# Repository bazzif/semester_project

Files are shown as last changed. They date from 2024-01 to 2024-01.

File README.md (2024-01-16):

# ElectorRing - Touch detection by coupling RF Signal to body

PCB

The electric ring can be used to detect the pinching of one's own fingers or the pinching of other people. The principle of operation is based on a transmitter that couples a high frequency signal into the body, which is measured by a receiver and amplified 30 times. This signal is then read by a microcontroller and can send a signal to a PC via BLE. 

Here is an overview of the outputs of the PCB that was developed as part of the semester project. It serves as an overview for debugging and pin 1 of the Seeed XIAO BLE must be connected to pin 1 of the PCB. 

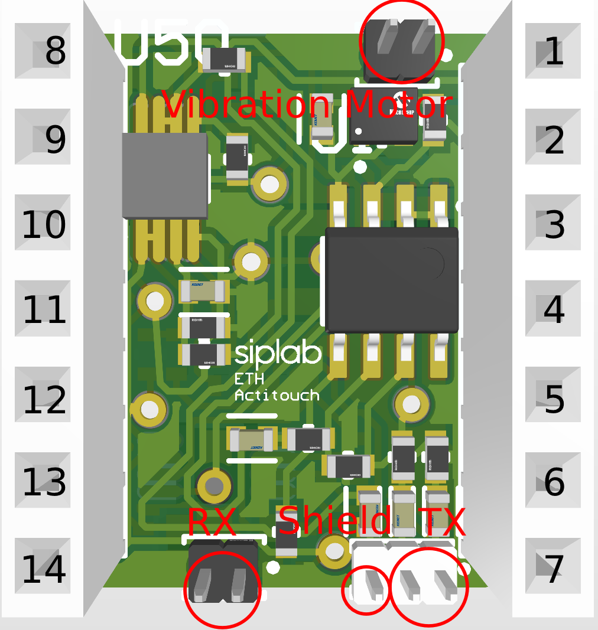
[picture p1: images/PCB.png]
PCB


## Assembly
- The assembly instruction can be found [here](https://github.com/eth-siplab-students/t-st-2022-WearableTouchDetection-FabioBazzi/blob/master/source/Insturctions/Assembly%20instructions.pdf) 
- Upload the [code](https://github.com/eth-siplab-students/t-st-2022-WearableTouchDetection-FabioBazzi/blob/master/source/firmware/BLEDataSendToPeripheral/BLEDataSendToPeripheral.ino) on the ring
- Upload the [code](https://github.com/eth-siplab-students/t-st-2022-WearableTouchDetection-FabioBazzi/blob/master/source/firmware/BLEMouseController/BLEMouseController.ino) on the Seeed XIAO BLE connected to your PC

## Callibration
It may be that the default programme does not work as desired because the ring was calibrated to me at the beginning, this section explains how I went about calibrating the ring.
- Connect the ring to the computer and [upload and run]([https://github.com/eth-siplab-students/t-st-2022-WearableTouchDetection-FabioBazzi/blob/master/source/Arduino%20Code/BLEDataSendToPeripheral/BLEDataSendToPeripheral.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](https://github.com/eth-siplab-students/t-st-2022-WearableTouchDetection-FabioBazzi/blob/master/source/Arduino%20Code/Callibration/Callibration.ino))
- Check what with the Serial Plotter of the Arduino what the Signal Strength of **Pinch** and **No Pinch** is
- Select the threshold value between pinch and no pinch. Set a suitable hysteresis to make the state more robust
- Edit the [code](https://github.com/eth-siplab-students/t-st-2022-WearableTouchDetection-FabioBazzi/blob/master/source/firmware/Callibration/Callibration.ino) and uplode

      #define HYST xx
      #define THRESHOLD xx 
      
## Further development
- Improve the ceramic filter problem by perhaps converting it to a high-pass filter that filters frequencies below a certain threshold.
- Instead of using the sum of the FFT to detect a detection, a digital Goertzel filter should be used. This requires less computing time than the FFT and is more frequency specific. That means instead of calculating the whole frequency spectrum only one frequency of the signal is not suppressed e.g. the undersampled 10.7 Mhz.
- Increase the sampling frequency of the Seeed XIAO BLE. Currently the sampling speed is limited by analog read. By rewriting the register of the microcontroller it should be possible to increase it up to 70 kHZ. 

## Debug
This section describes the bugs and debugging that I encountered while making the electro ring.
### Hardware
  - **Ceramic bandpass filter (10.7 MHZ):** It sometimes happened that the bandpass filter filtered the signal too much so that no signal could pass through the filter. In this case I have then shorted the filter with a cable .
  - **Soldering:** Make sure all solder joints are clean and in contact with the PCB. To test if the PCB is working, it is recommended to test the three sub-circuits (transmitter, receiver and shield) independently and see if they work. 
    - **Transmitter:** Connect ground to pin 2 and 3.3 V of the power supply to pin 3 and measure the signal at the transimitter output with the DSO. 

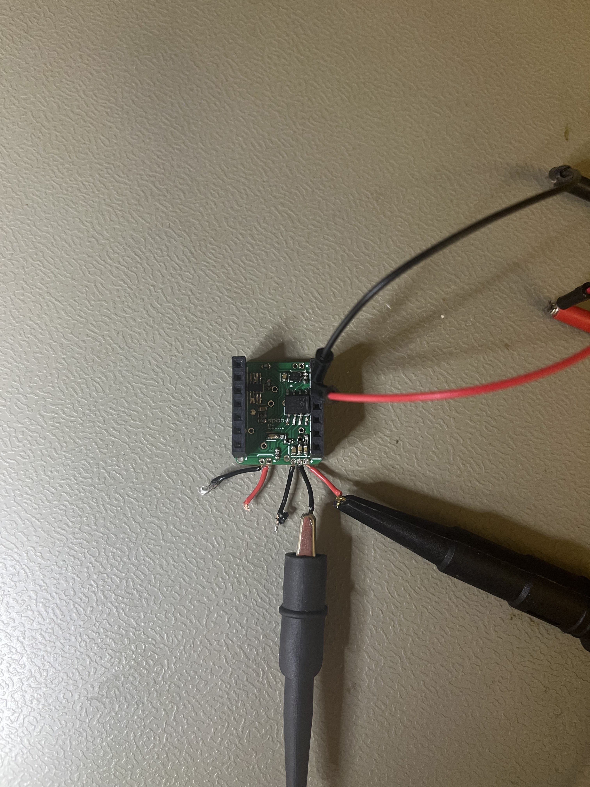
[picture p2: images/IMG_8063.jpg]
      
      
      The measured Signal should look similar to this:
      
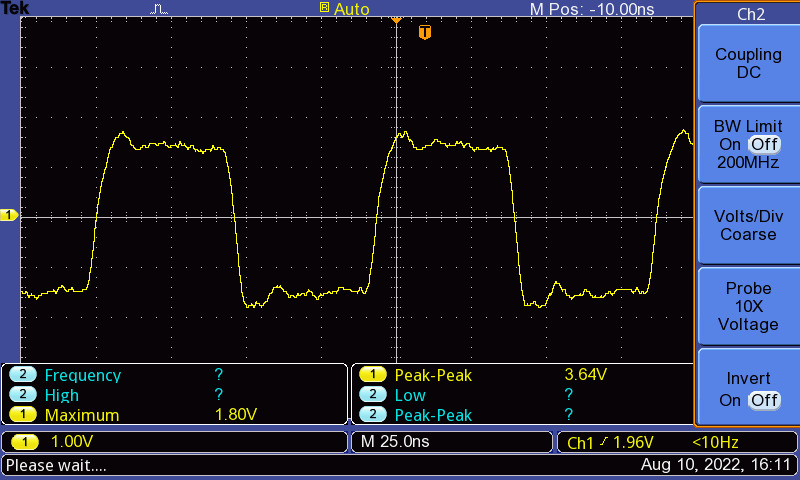
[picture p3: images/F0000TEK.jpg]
      
      
    - **Shield:** Connect ground to pin 2 and 3.3 V of the power supply to pin 3 and measure the voltage behind the capacitor which leads to the shield output.
    
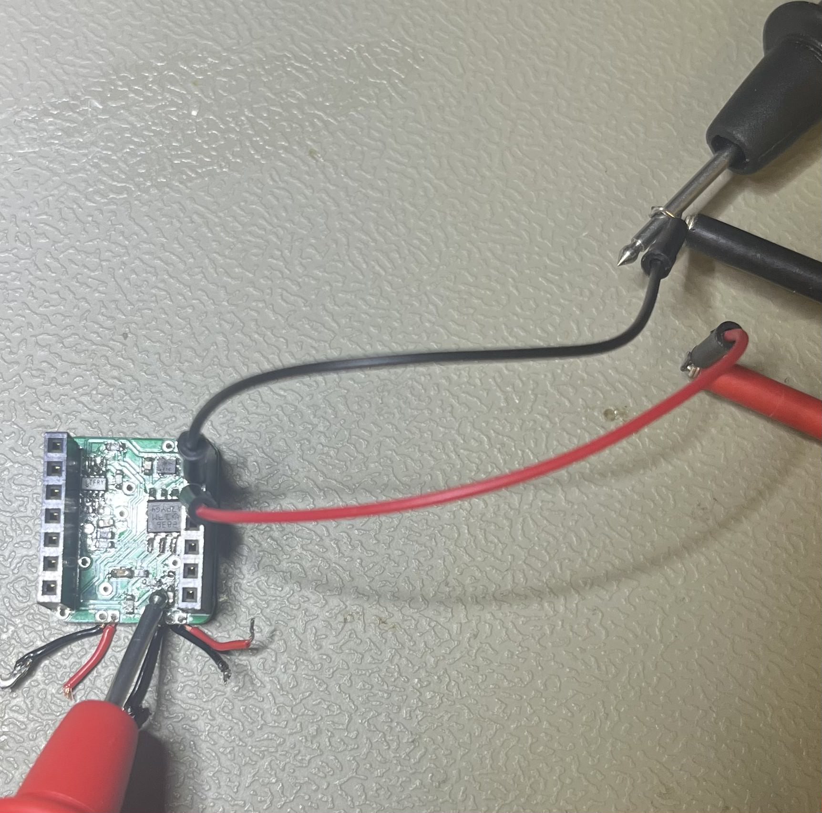
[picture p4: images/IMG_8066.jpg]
      
    
    - **Receiver:**  Connect ground to pin 2 and 3.3 V of the power supply to pin 3. Connect the frequency genrator with the receiver. Generate a sinusoidal signal with a frequency of 10.7 mhz and an amplitude of 50 mV. The gain of the receiver should amplify the signal by a factor of 30 and can be measured at pin 1 with the DSO.
    
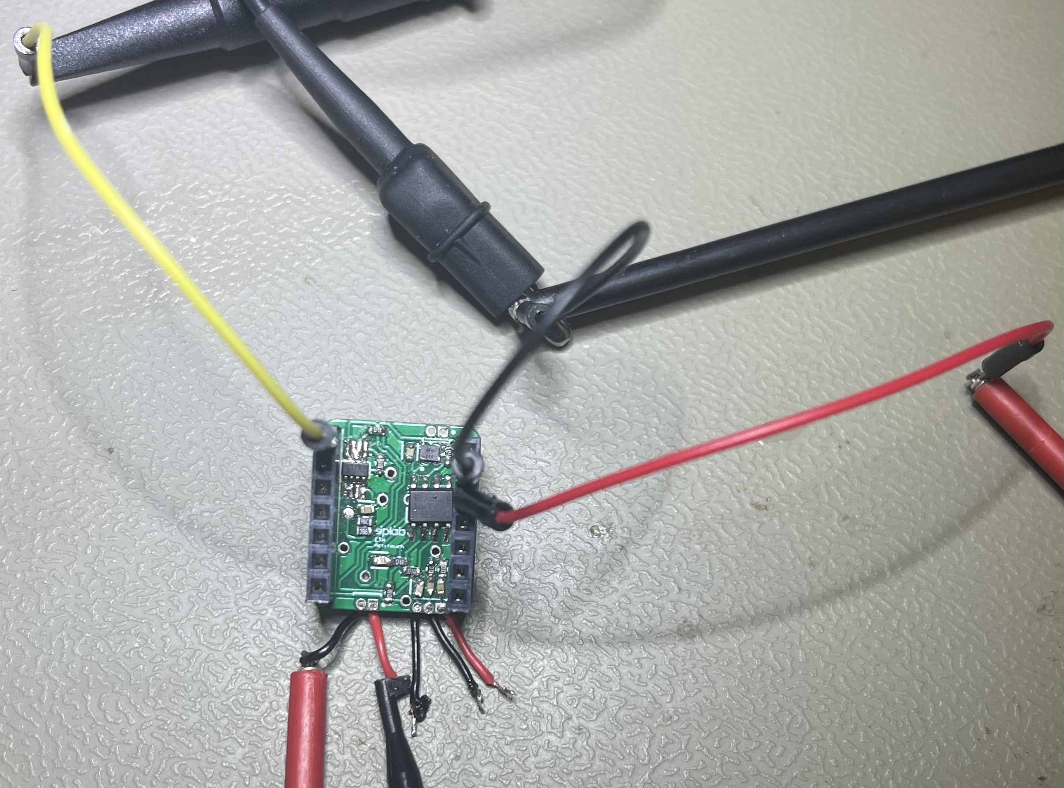
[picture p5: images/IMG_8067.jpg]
      
    
      The measured Signal should look similar to this:
    
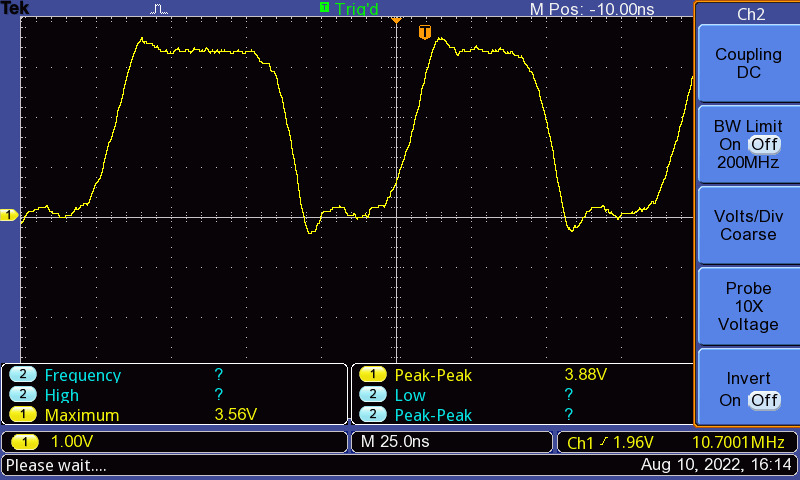
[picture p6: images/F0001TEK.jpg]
      
    
### Interface Seeed XIAO BLE and PC
 - **Board manager:** Make sure you have the latest version of Seeed XIAO BLE - nRF52840 board installed
 - **upload.tool.serial:** If you get the following error message when uploading your code to the Seeed XIAO BLE in the Arduino IDE 2.0.0, follow this [instruction](https://forum.arduino.cc/t/arduino-2-beta-12-stlink-programmer-error/921351) (at point 9. use this line **xiaonRF52840.upload.tool.default=nrfutil**)

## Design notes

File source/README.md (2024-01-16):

## Seeed XIAO BLE Code
The code for the Seeed XIAO BLE can be found in firmware it contains
- Calibration : Calculates the average of the DFT coefficients and visualizes them. Used to calibrate the ring for the carrier
- BLEMouseController : Makes connection to a second device and receives a pinch state and executes a mouse click on the computer 
- BLEDataSendToPeripheral : Make connection to a second device and detectes a pinch and send it
## Python Code 
A Python script to visualize measurements by recording the serial output of the Seeed XIAO BLE with Putty. There are 3 scripts
- Pinch_measurment.py : Visualization of the FFT coefficients for pinch and no pinch
- SNR.py : Visualization of the SNR for all three test subjects as a box plot
- Latency_measurement.py: Visualization of the Latency as a box plot
This folder also contains all the measurements that were performed with the electroring
## CAD
Contains all CAD files as STEP files and STL files to make the ring. There is also an additional gcode file that can be used directly to make a 3d print with the Ultimaker2+
## PCB
All flies to creat the PCB and generate a Part list as well as the schemas that are used to correctly assign the components to the PCB

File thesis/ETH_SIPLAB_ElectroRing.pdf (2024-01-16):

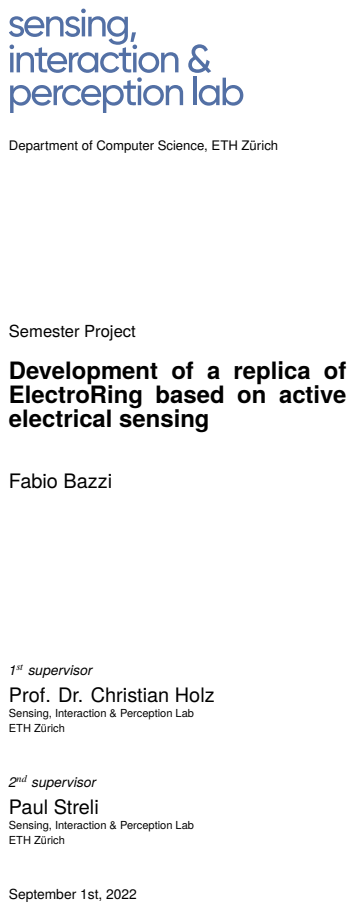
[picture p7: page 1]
Fabio Bazzi; nd supervisor Paul Streli; September 1st, 2022

Department of Computer Science, ETH Zürich

Semester Project
Development of a replica of
ElectroRing based on active
electrical sensing

st supervisor
Prof. Dr. Christian Holz

Sensing, Interaction & Perception Lab
ETH Zürich

Fabio Bazzi
Development of a replica of ElectroRing based on active electrical sensing
Semester Project, September 1st, 2022
Supervisors: Prof. Dr. Christian Holz and Paul Streli

ETH Zürich
Department of Computer Science, ETH Zürich Universitätstrasse 6
8092 Zürich

# Development of a replica of ElectroRing based on active electrical sensing

Fabio Bazzi
Sensing, Interaction & Perception Lab Department of Computer Science, ETH Zürich bazzif@ethz.ch

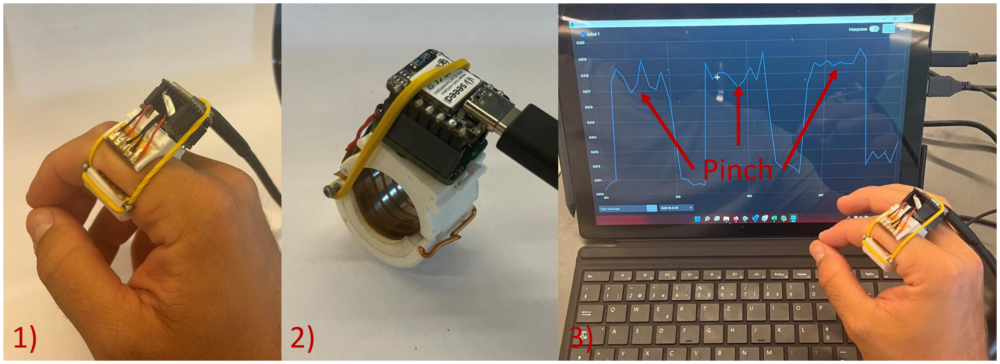
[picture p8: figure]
Pinch

Figure 1. 1) Replica of the ElectroRing worn on the index finger, 2) 3-D printed case with PCB mounted and flexPCB attached on the inside with a rubber band closure, and 3) Raw Real-time data from measured pinches.

ABSTRACT
As part of the semester project, a replica of the ElectroRing presented in the work of Kienzle et al. [1] was developed. The technology is based on electrically active sensing and is used to detect the creation of touches and the release of touches on the own body.

As part of the project, a printed circuit board (PCB) was developed that enables electronic active sensing. With a Seeed XAIO BLE the signal of the PCB was measured and processed with the discrete Fourier transform (DFT). Using a threshold, the signal is converted into a pinch state. This state is then sent to a peripheral device via BLE. All parts are held together by a 3D printed housing that can be attached to the index finger.

The replica of the ElectroRing was further tested for signal to noise ratio (SNR) with an average of 25 dB and an average latency of 130 ms. As an application example, the ring was configured to use a pinch as a mouse click input on the computer.

The documentation of the project is available at the following Github repository (https://github.com/eth-siplab-students/t-st-2022-WearableTouchDetection-FabioBazzi)

Keywords
Touch and pinch detection; mixed reality.

INTRODUCTION
Computers play an essential role in human interaction. Since the development of the personal computer, several waves of computer innovation have advanced computer technology. A new wave of innovation that integrate virtual reality (VR) and augmented reality (AR) into human daily life is emerging. [3]

Already today there are various devices that visualize VR and AR in high resolution, but the input devices that simplify interaction with VR and AR are not yet as advanced. [2]

The ElectroRing is an example of a VR and AR wearable interaction device. It can be used to detect pinching and touching the body as well as its release. This is especially useful in AR applications because it is difficult to detect touches with head mounted cameras when the fingers hover above the surface.

ElectroRing can therefore be used in AR applications. For example, a button can be projected on the human body and the pressing of the button can be measured with the ElectroRing.

The ElectorRing can not only be used for VR and AR applications, but it is also possible to use it with a personal computer to provide a new interaction experience for the user.

This technology has many application potentials, which makes the ElectroRing interesting for the research group SIP of the

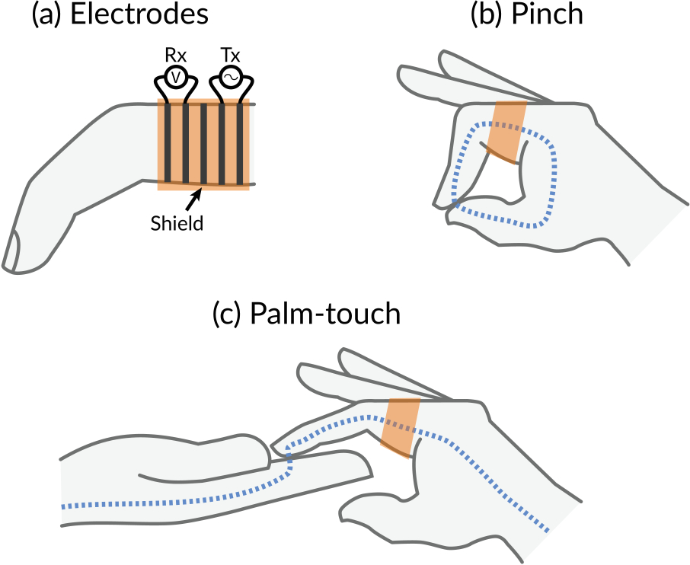
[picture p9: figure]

Figure 2. “(a) ElectroRing uses five electrodes: two transmit electrodes (closest to the palm) differentially couple the AC signal to the finger, the middle electrode shields direct coupling between the Tx and Rx electrodes, two receive electrodes (distal) measure the gradient of the signal along the finger. (b) During a pinch, the signal travels through the thumb and galvanically back to the transmit electrode. (c) Touching the opposing palm creates a galvanic path through the body back to the proximal transmit electrode. ” [1]

ETH Zurich and therefore a replica of the ElectroRing was created in this project.

Theory of Operation
In Figure 2 the theory of operation of ElectroRing is shown. In summary, the ring works by coupling a 10.7 MHz square wave of 3.3 volts with two transmitting electrodes on the body. When no galvanic contact between the transmitter and the receiver (e.g. Pinch or Palm-touch) exists most of the signal flows between the two transmitter electrodes. An electrical shield in the middle prevents the transmitter to directly couple with the receiver. When a galvanic path is closed by a pinch, the two receiver electrodes measure the gradient of the signal along the finger.

For more and deeper explanation on the principle of effect, the work of Kienzle et al. [1] is recommended.

RELATED WORK
There are already various systems for segmenting touches, with an electro active sensing system. The work of Kienzle et al. [1] is about the ElectroRing which served as a basis to create a replica in this semester project. In another work of Zahng et al. [5] a bracelet is used, called ActiTouch. The ElectroRing is based on the ActiTouch, but it has an electrical shield between the receiver and the transmitter. Therefore the ElectroRing simplifies instrumentation by requiring only one instrumentation location instead of two as the ActiTouch does.

ElectroRing
The paper describes the principle of operation, the production of the ElectroRing and measurement results. In addition, the ring described in the paper has an integrated IMU-2-D tracking system, with which they concluded that the sensing technology is largely independent of gestures velocity or the mechanical action at contact with a 25 dBV SNR. They have also shown in further work that there is a potential to use the ElectroRing to detect various electrically conductive materials by touch. [1]

ActiTouch
With ActiTouch, the transmitter electrodes are attached to a wristband and receiver electrodes are attached to a headmounted display. ActiTouch, unlike ElectroRing, does not include an active shield. This causes the receiver electrode to become saturated when the transmitter and receiver electrodes are close together, resulting in poor sensitivity to touch. This makes it impossible to incorporate active electronic sensing technology in a single small device. According to their paper, the best material for the electrodes is silver fabric which are galvanically arranged longitudinally to each other. Further they have shown with a frequency swept that the best signal to noise results are reached at the frequency 10.5 MHz. Also they have not found negative health effects on the human body using this measurement principle. [5]

IMPLEMENTATION
Hardware and software was developed for the replica of ElectroRing. In order for the replica of ElectroRing to measure signals and communicate with peripheral devices, a micro controller was used. Further, a printed circuit board (PCB) was designed, which contains signal generation, the electrical shield and a measurement gain. In addition, a ring was designed to hold all the parts together and to attach the system to the finger in a portable way. The hardware was then programmed which allows to measure a pinch state and to send it to a peripheral device. Finally, an application example was created to demonstrate the potential of the replica of ElectroRing and measure latency. 4

Hardware
Electronics
The electronics of the replica of ElectroRing consist of a PCB and a Seeed XIAO BLE. The PCB is used for signal generation and amplification and the Seeed XIAO BLE is used for measurement and communication. The PCB contains a transmitter, receiver and a shield. The transmitter generates a 3.3V 10.7 MHz rectangular signal that is then coupled to the body over electrodes. The receiver is an instrumentation amplifier with a gain of 30 and with electrodes contacted to the body. Located between receiver and transmitter is the shield electrode with a potential of 1.65 volt. The electronics are powered by a 3.7 V battery with 40 mAh. The current for the operation was measured with a Fluke 115 and is 60 mA, therefore the replica of ElectroRing can be theoretically be powered for 40 minutes.

Housing
The housing to hold and attach the PCB to the finger is 3-D printed with PLA. A flexPCB with a conductor width of 2 mm and a distance of 1 mm between the conductor paths is used to connect the receiver, transmitter and shield to the finger. A sealing material is glued inside the ring to ensure the contact of the conductive lines with the finger and to increase the wearing

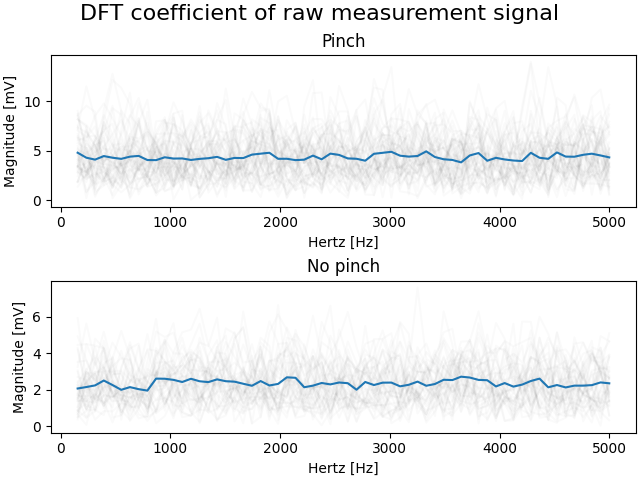
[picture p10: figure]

Figure 3. The blue line is the mean value of the DFT coefficient for multiple measurement bins, while the black lines are the DFT coefficients for consecutive bins of 128 samples, the signal was sampled at 10 kHz.

comfort. With double sided tape the flexPCB is attached to the seal. The ring is closed by means of a rubber band.

Software
The signal of the receiver is undersampled with the Seeed XIAO BLE’s maximum standard sampling rate of 10 kHz. The original intention was to calculate the DFT coefficients by using 128 samples to determine a frequency range that rises during pinching, and then to use a Goertzel filter to filter the frequency associated with the pinch. However, when evaluating the DFT coefficients, no particular frequency could be found which increased alone when the galvanic path was closed. It was found that all coefficients except the first coefficient, which belongs to the DC current, changed significantly when pinched, as one can see in Figure 3. For this reason, the average of the DFT coefficients, except the first coefficient, was calculated. When the average of the DFT coefficients exceeded a medium threshold with hysteresis, a pinch state is detected. If this is undershot, a pinch release is detected. However, these values do not work unconditionally for every user and the replica of the ElectroRing must be recalibrated after the user changes.

EVALUATION
Two evaluations were performed using the replica of the ElectroRing.
1. Latency measurement
2. Signal to noise ratio (SNR) measurement

Apparatus for latency
To measure the latency, the ring was attached to the index finger. In the front of a screen of the computer with a visible running power point presentation, the index finger was filmed with an iPhone 12 Pro in slow motion with 240 FPS. By pinching the finger the Seeed XIAO BLE detected the pinch and sent it a via BLE to a second Seeed XIAO BLE connected to the Computer. The second microcontroller connected to the
Test subject | Threshold [mV] | Hysteresis [mv]
1 | 0.016 | 0.003
2 | 0.011 | 0.02
3 | 0.013 | 0.002

Table 1. Threshold and hysteresis values for the three test subjects

Test subject | mean | SD
1 | 15.81 dB | 0.40
2 | 29.72 dB | 0.39
3 | 28.73 dB | 0.47

Table 2. Mean and SD of SNR for all test subjects

computer generated a mouse click. Thus a change of slides was triggered. The latency can be calculated by the frame rate and counting the number of frames that elapse between the pinch and the slide change.

Apparatus for SNR
The SNR was measured for 3 different people with the ElectroRing attached to the index finger. The ElectroRing was initially calibrated for each person connected to the computer. The ring is calibrated by considering the signal described in subsection 3.2 for pinch and no pinch for a given person, then both middle threshold and hysteresis are set empirically. The values can be seen in Table 1. The three different test subjects had to switch five times between pinch and non-pinch state. The signal from subsection 3.2 was recorded and saved with PuTTY to the disk and the SNR was calculated according the equation Equation 1.

SNR = 20log10(

mean(vtouch)−mean(vno−touch)

SD(vnoise)

) (1)

“vtouch are samples from a touch segment, vno−touch are samples from a non-touch segment, and vnoise are samples from the preceding non-touch segment.”[1].

RESULTS
The data generated from the replica of the ElectroRing evaluation was processed in Python, using the packages Pandas, Scipy and Matplotlib.

Latency
The result of the latency measurement is shown in Figure 4 as a box plot. On average the latency is 130 milliseconds (ms) (SD = 21 ms) to detect a pinch, send it to a second device and execute an input action on a personal computer.

Signal to Noise
The results of the SNR measurements are shown in Figure 5. The mean and SD are summarized in Table 2.

Every pinch was detected correctly, so the precision given Equation 2 and recall given Equation 3 were perfect.

precision =

TP
TP+FP

(2)

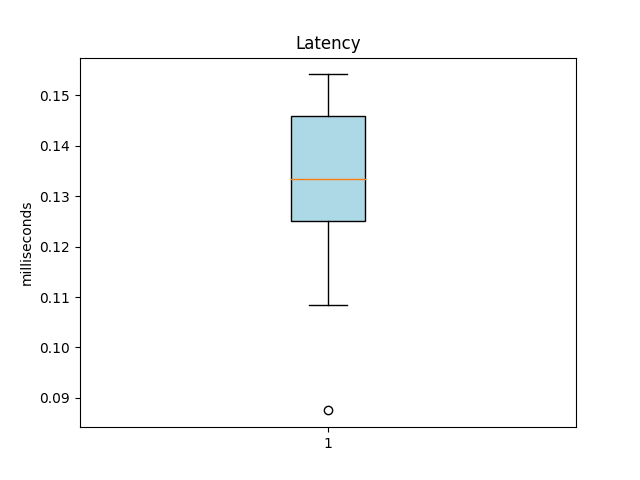
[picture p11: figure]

Figure 4. Measured latency due to pinch to trigger an action on the personal computer

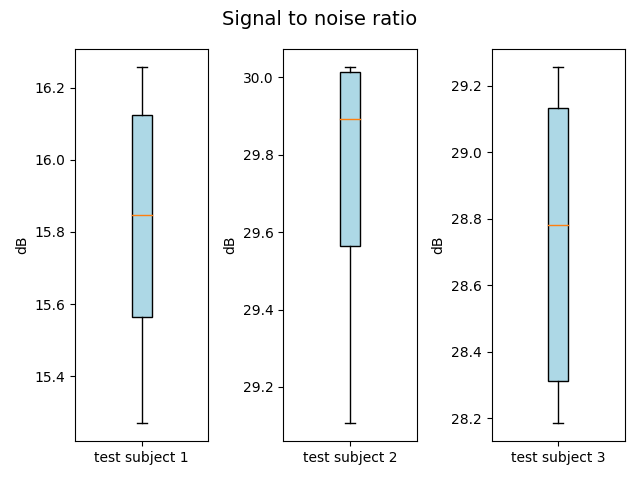
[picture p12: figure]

Figure 5. Caption

precision =

TP
TP+FN

(3)

With:

true positive (TP) : Pinch correctly detected

false positive (FP) : Pinch falsely detected

false negative (FN) : Pinch not detected

DISCUSSION
In this project, a replica of ElectroRing was built to detect touch. The viability of the ring was validated in two experiments. With a latency of 130 ms (SD = 21ms), the latency is acceptable based on the work of Ritter et al. [4]. Furthermore, the SNR of over 15 dB provides a sufficiently robust touch detection with a perfect recall and precision. However, it must be taken into account that the threshold and hysteresis must be individually tuned to detect touch.

Both latency and SNR can be further optimized by improving the software of the replica of ElectroRing. Instead of calculating the average of all DFT coefficients except the first, it could be more useful to determine the exact frequency band that rises during pinching and then to filter it with an appropriate bandpass filter. This partially reduces the computation time of the code and improves latency. It also improves the robustness. If all DFT coefficients except the first are considered, other signals with a different operating frequency than the ElectroRing that are coupled to the body can also have an influence. This on the other hand simplifies the tuning of the ring and makes it even more robust and user-friendly. One approach could be to increase the sampling rate when reading the signal to determine a unique frequency and then filter it with a Gortzel filter to detect touch.

If the replica of the ElectroRing is operated by the computer there are no misdetections of a pinch. When powered only by the battery and not connected to the computer, misdetections occur but only rarely. This may be due to the fact that the ring is powered by 5 volts when connected to the computer, and 3.7 volts when powered by the battery. To see how the behaviour of the ring changes when powered by the battery, the next step should be to transmit not only the pinch state via BLE, but also the signal described in subsection 3.2.

CONCLUSION
During the semester project, a Working MVP of the ElectroRing was developed based on the work of Kienzle et al. [1]. With the evaluation it was shown that the SNR is sufficient to detect the pinch state reliably. Further, with a low latency it was shown that the responsiveness of the ring is sufficient to ensure a acceptable human computer interaction.

REFERENCES
[1] Wolf Kienzle, Eric Whitmire, Chris Rittaler, and Hrvoje Benko. 2021. Electroring: Subtle pinch and touch detection with a ring. In Proceedings of the 2021 CHI

Conference on Human Factors in Computing Systems. 1–12.

[2] Hai-Ning Liang, Yuwei Shi, Feiyu Lu, Jizhou Yang, and Konstantinos Papangelis. 2016. VRMController: an input device for navigation activities in virtual reality environments. In Proceedings of the 15th ACM SIGGRAPH Conference on Virtual-Reality Continuum and Its Applications in Industry-Volume 1. 455–460.
[3] Stylianos Mystakidis. 2022. Metaverse. Encyclopedia 2, 1 (2022), 486–497.
[4] Walter Ritter, Guido Kempter, and Tobias Werner. 2015. User-Acceptance of Latency in Touch Interactions. In Universal Access in Human-Computer Interaction. Access to Interaction, Margherita Antona and Constantine Stephanidis (Eds.). Springer International Publishing, Cham, 139–147.
[5] Yang Zhang, Wolf Kienzle, Yanjun Ma, Shiu S Ng, Hrvoje Benko, and Chris Harrison. 2019. ActiTouch: Robust touch detection for on-skin AR/VR interfaces. In Proceedings of the 32nd Annual ACM Symposium on User Interface Software and Technology. 1151–1159.

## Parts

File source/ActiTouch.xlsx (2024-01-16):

Comment | Description | Designator | Footprint | LibRef | Quantity | Price/Pice [CHF] | Price [CHF] | Link
LS4448GS08 | Schottky Barrier Diode, 2-Pin SOD-323, Pb-Free, Tape and Reel | D1 | ONSC-SOD-323-2-477-02_V | CMP-1055-00462-1 | 1 | 0.18 | 0.18 | https://www.digikey.ch/de/products/detail/vishay-general-semiconductor-diodes-division/LS4448GS08/4810586
LT Q39E-Q1OO-25-1 | LED GREEN 0603 SMD | D? | FP-6_541-5056_01-4-MFG | CMP-02520-000009-1 | 1 | 0.42 | 0.42 | https://www.digikey.ch/de/products/detail/osram-opto-semiconductors-inc/LT-Q39E-Q1OO-25-1/2793415
CDSCB10M7GA121-R0 | Ceramic Filter 10.7MHz 2-Pin Surface Mount Emboss T/R | FL1 | FP-CDSCB10M7GA121-R0-MFG | CMP-06047-000004-1 | 1 | 1.11 | 1.11 | https://www.digikey.ch/de/products/detail/murata-electronics/CDSCB10M7GA135-R0/1219357
SSQ-107-01-G-S | SQ Post Socket, Through-hole, Vertical, -55 to 125 degC, 2.54 mm Pitch, 7-Pin, Female, RoHS | J1, J2 | SMTC-SSQ-107-01-X-S | CMP-1023-00284-1 | 2 | 1.46 | 2.92 | https://www.digikey.ch/de/products/detail/samtec-inc/SSQ-107-01-G-S/1110612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
GRPB021VWVN-RC | CONN HEADER VERT 2POS 1.27MM | J3 | FP-GRPB021VWVN-RC-MFG | CMP-2000-06371-2 | 1 | 0.24 | 0.24 | https://www.digikey.ch/de/products/detail/sullins-connector-solutions/GRPB021VWVN-RC/1786438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
Inductor | Inductor | L? | 0402-A | Inductor | 1 |  | 0
S2B-PH-SM4-TB(LF)(SN) | Male Header, Pitch 2 mm, 1 x 2 Position, Height 5.5 mm, -25 to 85 degC, RoHS, Tape and Reel | P? | JST- S2B-PH-SM4-TB(LF)(SN)-2_V | CMP-1755-00001-1 | 1 | 0.52 | 0.52 | https://www.digikey.ch/de/products/detail/jst-sales-america-inc/S2B-PH-SM4-TB-LF-SN/926655
DMG2302UK-7 | MOSFET N-CH 20V 2.8A SOT23 | Q? | FP-SOT23-MFG | CMP-12801-000001-1 | 1 | 0.36 | 0.36 | https://www.digikey.ch/de/products/detail/diodes-incorporated/DMG2302UK-7/6010142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
CRCW060311K5FKEA | RES Thick Film, 11.5kΩ, 1%, 0.1W, 100ppm/°C, 0603 | R? | FP-CRCW0603-e3-IPC_B | CMP-2000-03864-2 | 1 | 0.1 | 0.1 | https://www.digikey.ch/de/products/detail/vishay-dale/CRCW060311K5FKEA/1174788
CRCW060318K7FKEA | RES Thick Film, 18.7kΩ, 1%, 0.1W, 100ppm/°C, 0603 | R? | FP-CRCW0603-e3-IPC_C | CMP-2000-02962-2 | 1 | 0.1 | 0.1 | https://www.digikey.ch/de/products/detail/vishay-dale/CRCW060318K7FKEA/1174811
EVPAF7B70 | SWITCH TACTILE SPST-NO 0.02A 15V | SW? | FP-EVPAF7B70-MFG | CMP-05618-000093-1 | 1 | 0.5 | 0.5 | https://www.digikey.ch/de/products/detail/panasonic-electronic-components/EVP-AF7B70/3182276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
SeeeduinoXIAO |  | U | Seeeduino XIAO-MOUDLE14P-2.54-21X17.8MM | SeeeduinoXIAO | 1 | 5.35 | 5.35 | https://www.digikey.ch/de/products/detail/seeed-technology-co-ltd/102010428/14672129
REG102NA-3.3/3K | Single Output Fast Transient Response LDO, 250 mA, Fixed 3.3 V Output, 1.8 to 12 V Input, 5-pin SOT-23 (DBV), -55 to 125 degC, Green (RoHS & no Sb/Br) | U1 | DBV0005A_N | CMP-0394-00176-2 | 1 | 2.82 | 2.82 | https://www.digikey.ch/de/products/detail/texas-instruments/REG102NA-3-3-3K/362404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
LTC6253ITS8#TRMPBF | Dual Channel, Power Efficient Operational Amplifier, RRIO, 720 MHz Typical GBW, 280 V/us Typical SR, 2.5 to 5.25 V, 8-Pin SOP (TS8-8), Industrial, Pb-Free, Mini Reel | U10, U20, U21 | LT-TS8-8-TSOT-23_V | CMP-0359-03726-2 | 3 | 7.51 | 22.53 | https://www.digikey.ch/de/products/detail/analog-devices-inc/LTC6253ITS8-TRMPBF/2399167
OPA2836IDR | Dual, Very Low Power, Rail to Rail Out, Negative Rail In, VFB Operational Amplifier, 2.5 to 5.5 V, -40 to 85 degC, 8-pin SOIC (D8), Green (RoHS & no Sb/Br) | U? | D0008A_M | CMP-0018-00293-2 | 2 | 4.09 | 8.18 | https://www.digikey.ch/de/products/detail/texas-instruments/OPA2836IDR/2799311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
DSC6003MI2A-010.7000T | DSC6003MI2A-010.7000T | Y1 | FP-C04-1202-MFG | CMP-06255-000006-1 | 1 | 1.19 | 1.19 | https://www.digikey.ch/de/products/detail/microchip-technology/DSC6003MI2A-010-7000T/8639112
C0820BE03L27 |  |  |  |  | 1 | 2.77 | 2.77 | https://www.digikey.ch/de/products/detail/ineed-motor/C0820BE03L27/15796037
 |  |  |  |  |  |  | 49.29

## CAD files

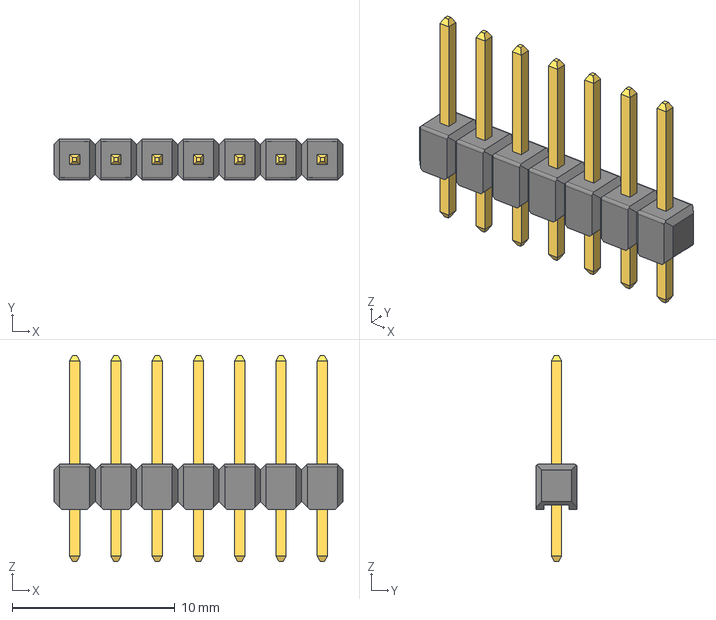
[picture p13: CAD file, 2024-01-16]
source/CAD/STEP Files/Pin Header 1x7 TH Pitch 2.54mm.stp
17.8 x 2.54 x 12.7 mm

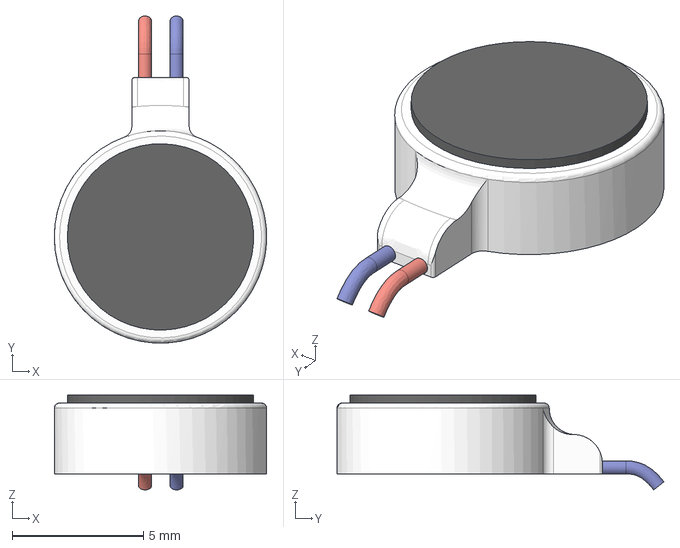
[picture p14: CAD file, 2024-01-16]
source/CAD/STEP Files/Vibration Motor v1.step
8.08 x 12.4 x 3.61 mm

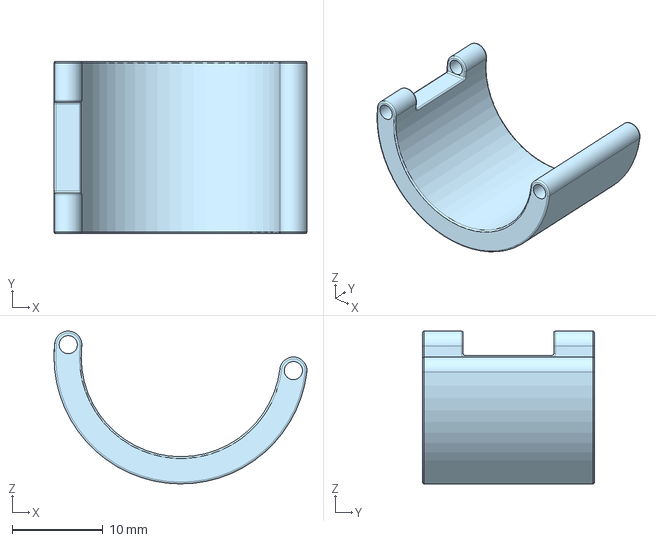
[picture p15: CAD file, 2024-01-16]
source/CAD/STEP Files/Locking.step
27.9 x 19.0 x 16.9 mm

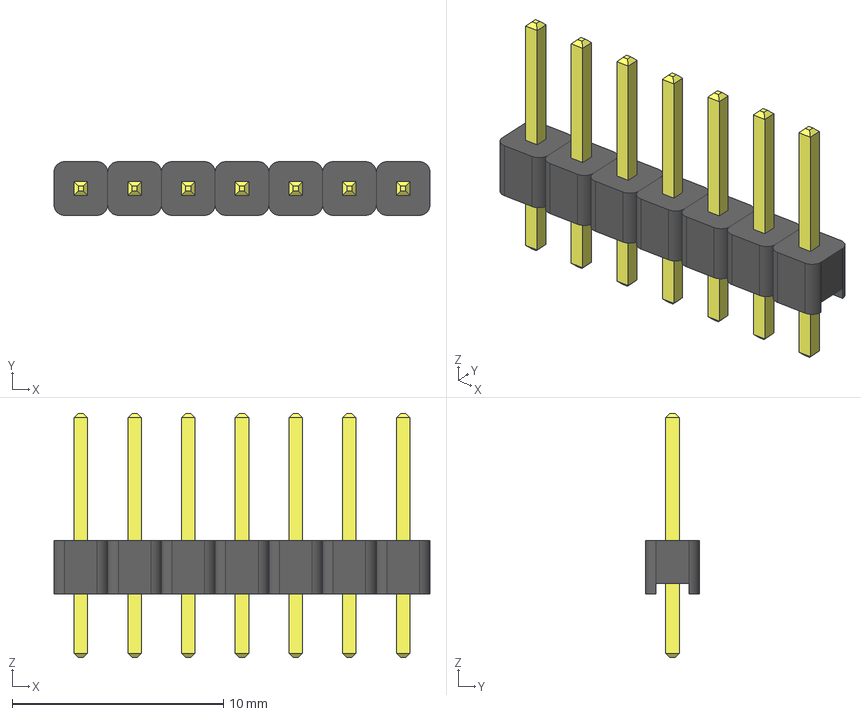
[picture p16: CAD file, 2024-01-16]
source/CAD/STEP Files/BPSC-07.stp
17.8 x 2.54 x 11.5 mm
Pino
Base
Pino001
Base001
Pino002
Base002
Pino003
Base003
Pino004
Base004
Pino005
Base005
Pino006
Base006

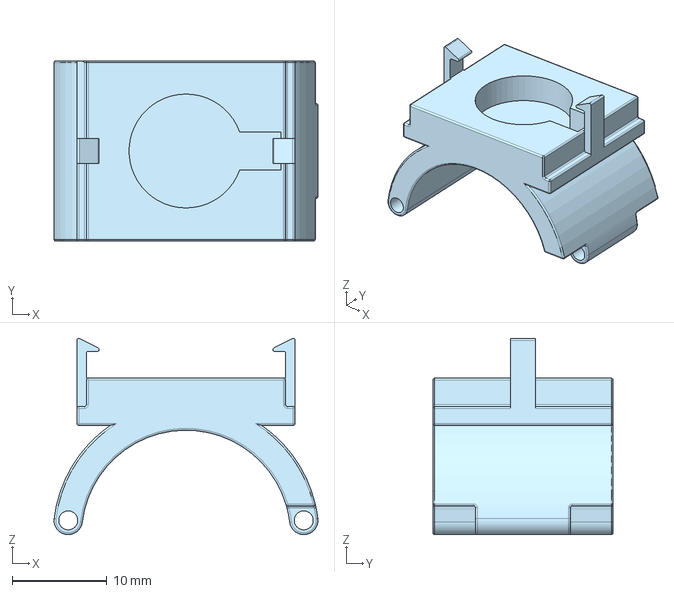
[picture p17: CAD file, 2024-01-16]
source/CAD/STEP Files/PCBAdapter.step
27.8 x 19.0 x 20.7 mm

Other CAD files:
source/CAD/STL Files/Locking.stl
source/CAD/STL Files/PCB_Adapter.stl

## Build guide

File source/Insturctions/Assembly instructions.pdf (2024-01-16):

# Assembly instructions

This is a documentation of the production of the ring

## What you need:

- 3-D Print of Ring
- Felx PCB
- Cables
- PCB
- Screwes M 1.8
- Seeed XIAO BLE (Sense)
- Battery 40 mAh

## 1. Step

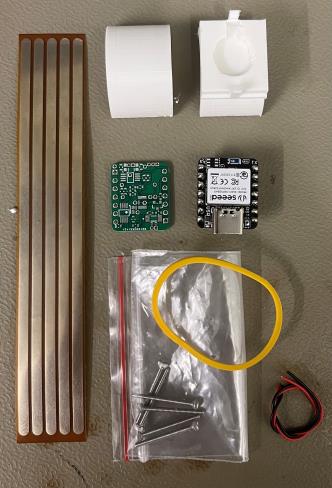
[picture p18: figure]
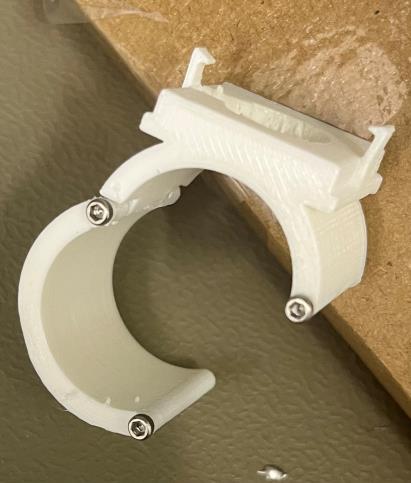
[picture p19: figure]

Fasten the two halves of the ring with a screw and a nut. Glue the screws into the four holes on the opposite side so that the screw head has a small distance to the ring (so that the rubber is better clamped).

## 2. Step

Solder the PCB together with the help of the Altium Files, there is also a Parts list in https://github.com/eth-siplab-students/t-st-2022-WearableTouchDetection-FabioBazzi/tree/master/source/PCB/PCB-Final

## 3. Step

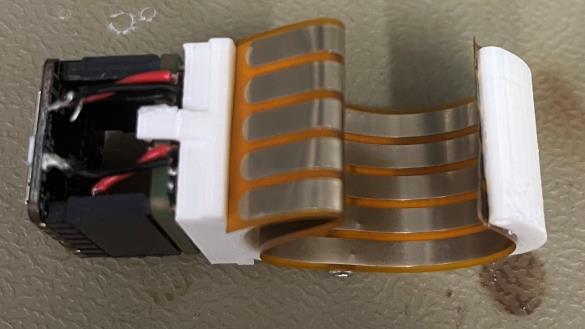
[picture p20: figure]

Using double-sided tape, attach the Flex PCB to the ring. If the Flex PCB does not make contact with the finger, an additional sealing material can be glued between the ring and the Flex PCB.

## 4. Step

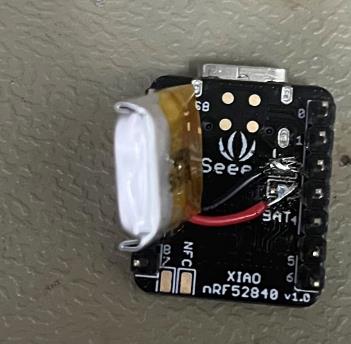
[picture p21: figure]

Connect the battery to the Seeed XIAO BLE (Sense)

## 5. Step

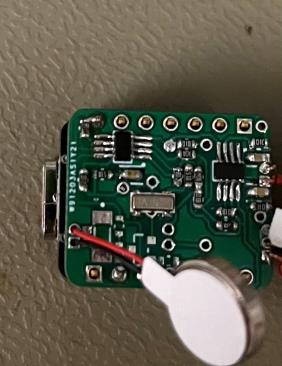
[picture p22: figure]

Connect the vibration motor to the PCB

## 6. Step

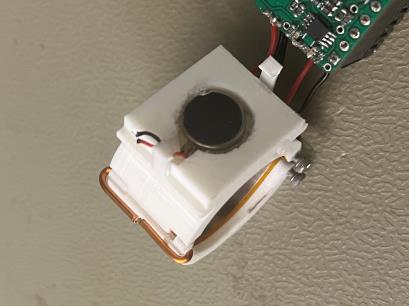
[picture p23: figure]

Glue the vibration motor into the housing (I used hot glue)

## 7. Step

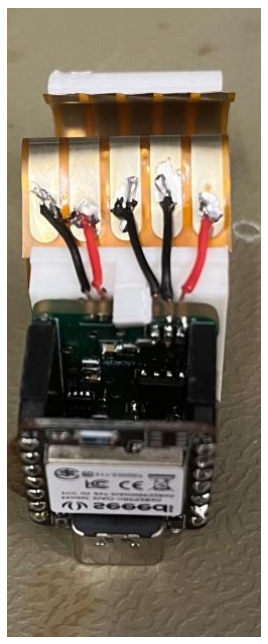
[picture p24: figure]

Connect the transmitter, the shield and the receiver as follows on the picture. You can now load the following codes onto the microcontroller.

## 8. Step

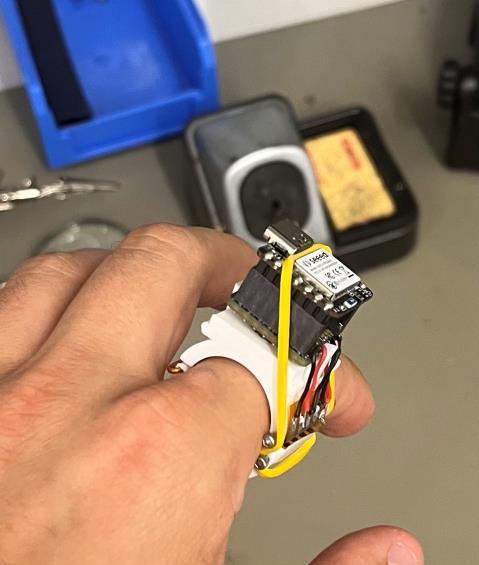
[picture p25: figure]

The rubber band can now be clamped to close the ring

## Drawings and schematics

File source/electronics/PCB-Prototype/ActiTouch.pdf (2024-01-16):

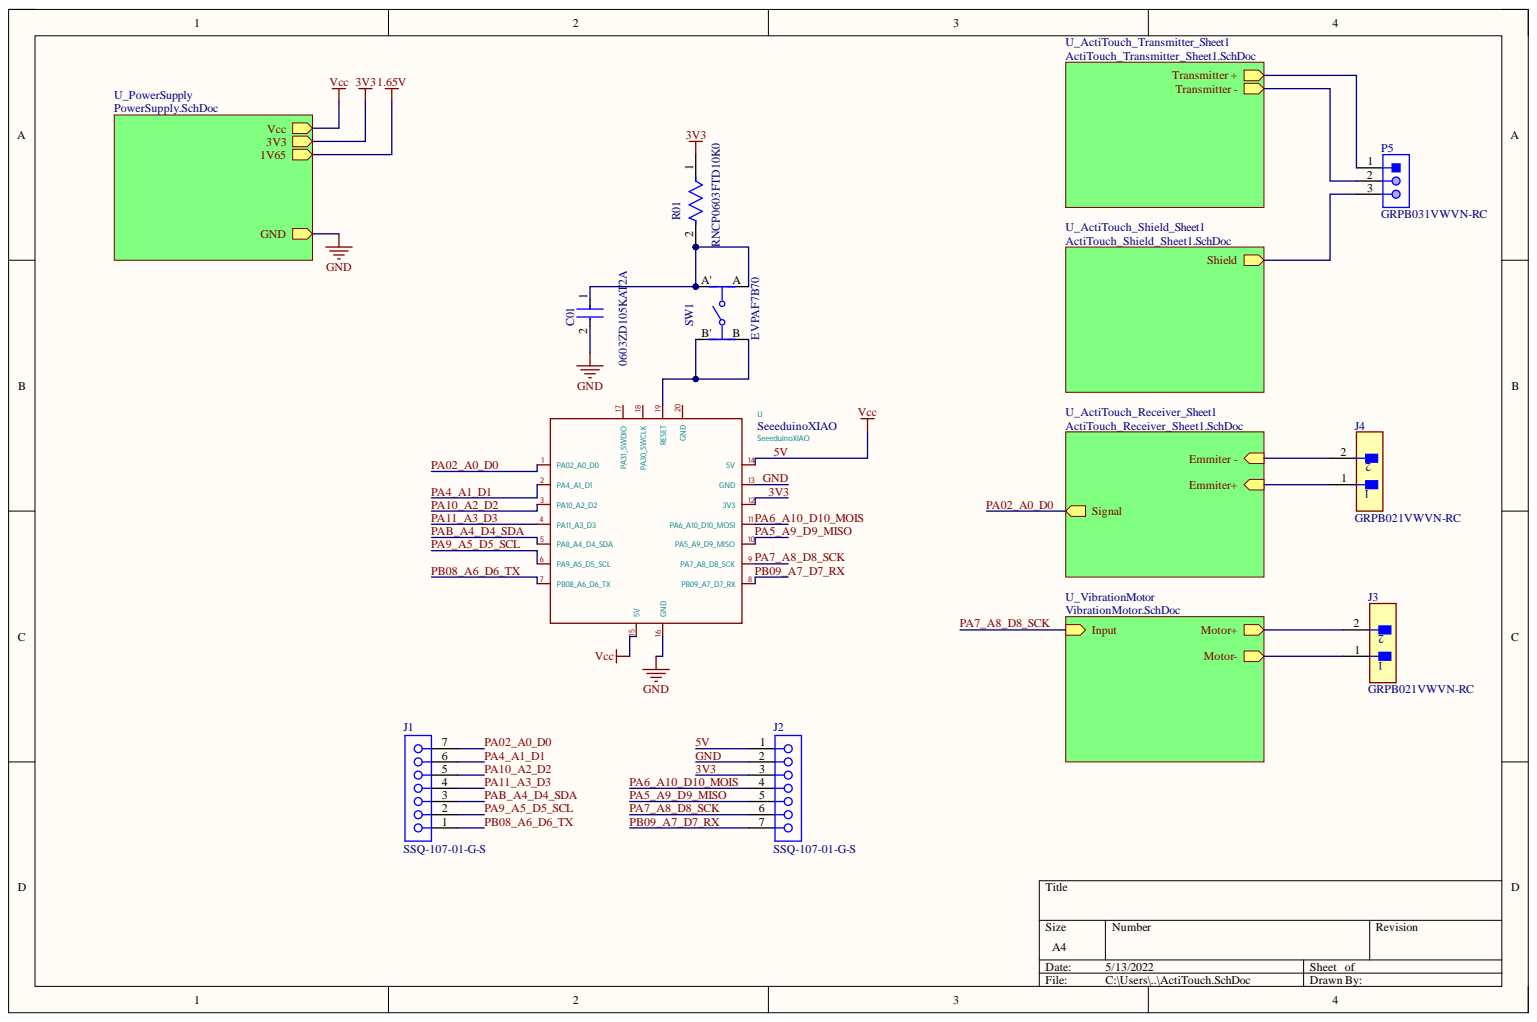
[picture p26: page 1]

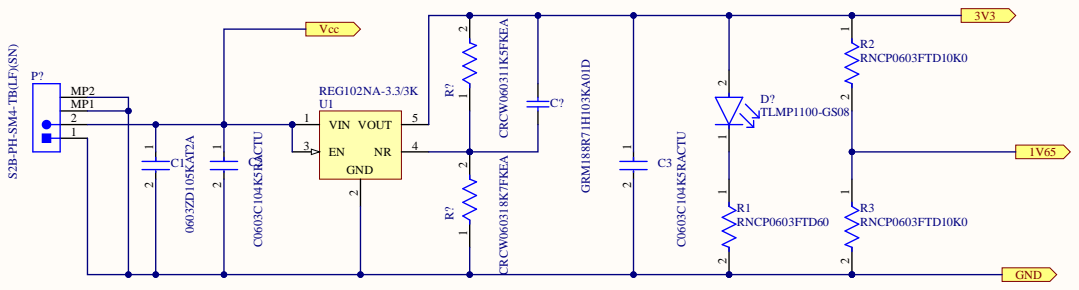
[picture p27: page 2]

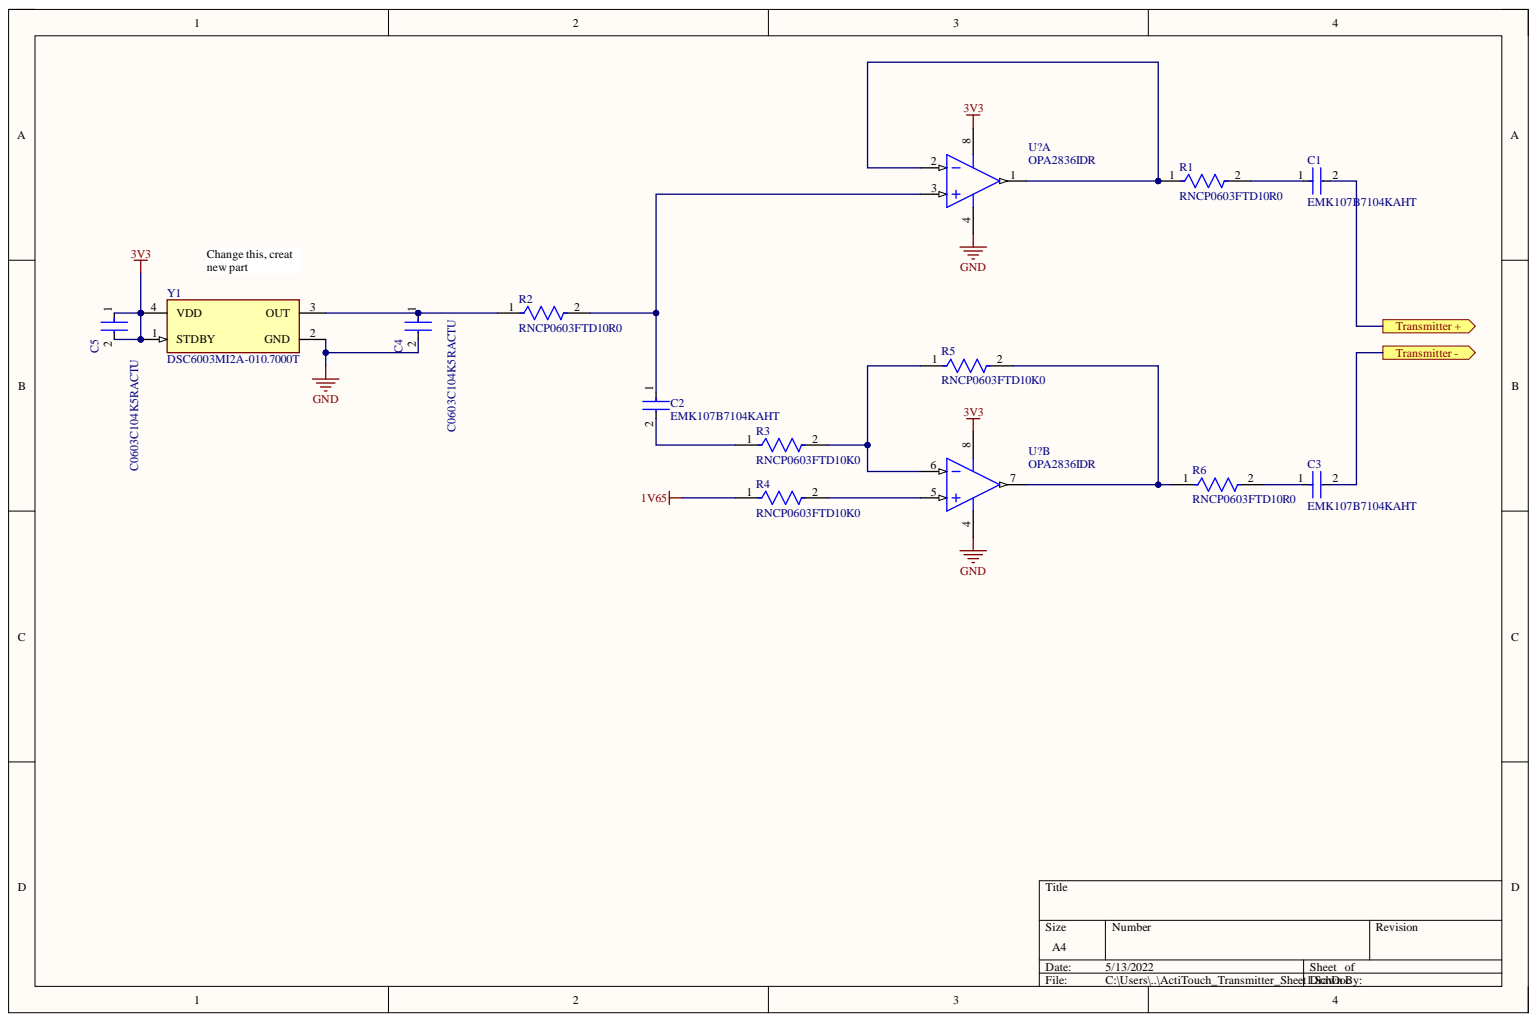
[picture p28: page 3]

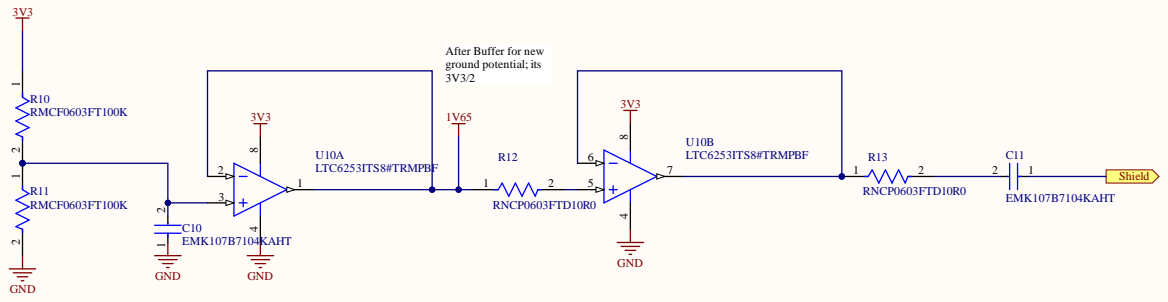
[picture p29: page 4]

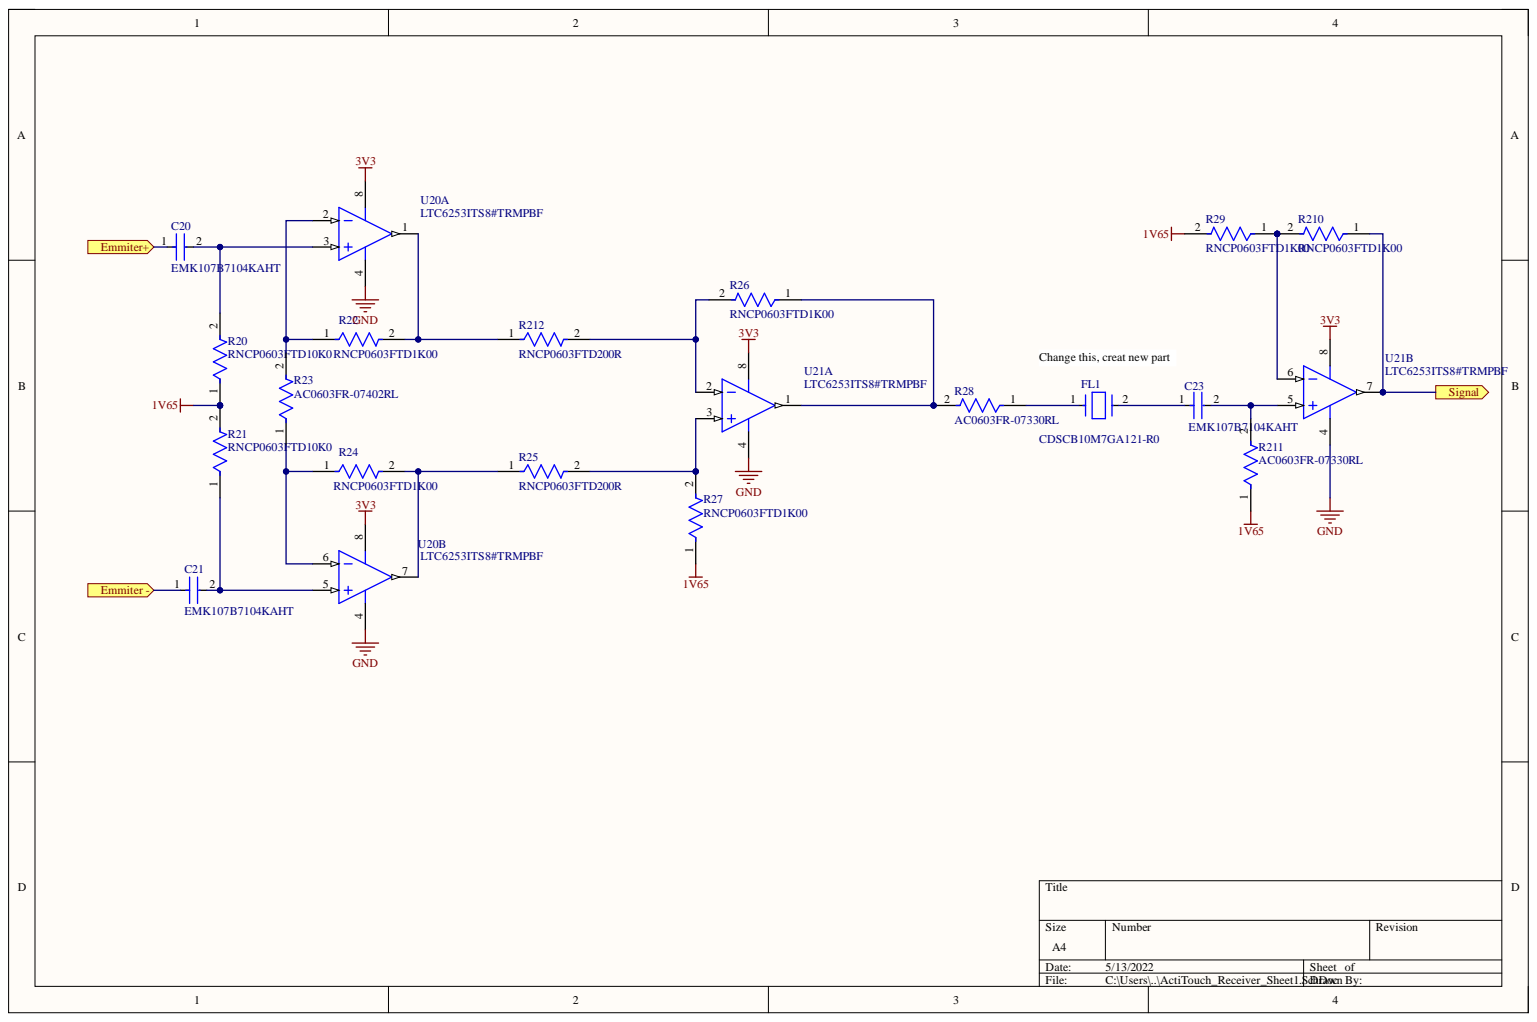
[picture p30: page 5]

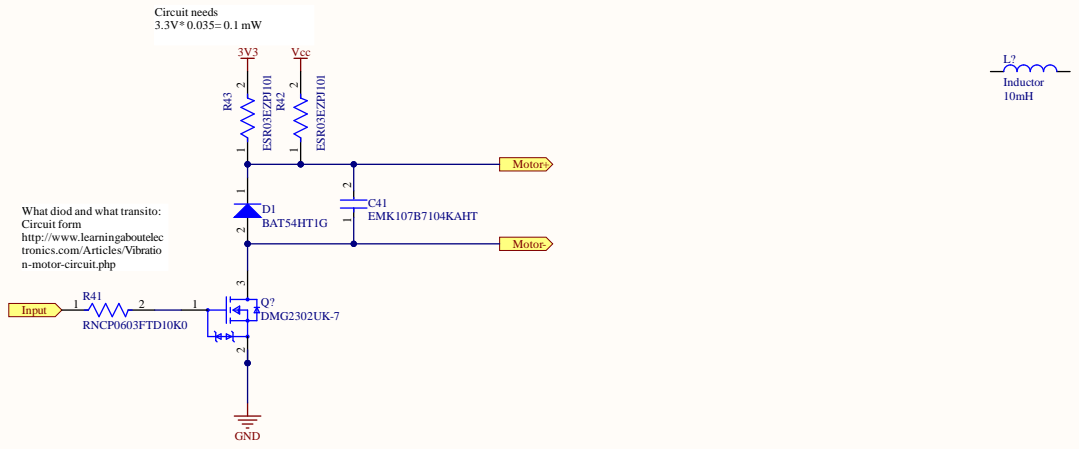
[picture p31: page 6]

What diod and what transito:
Circu

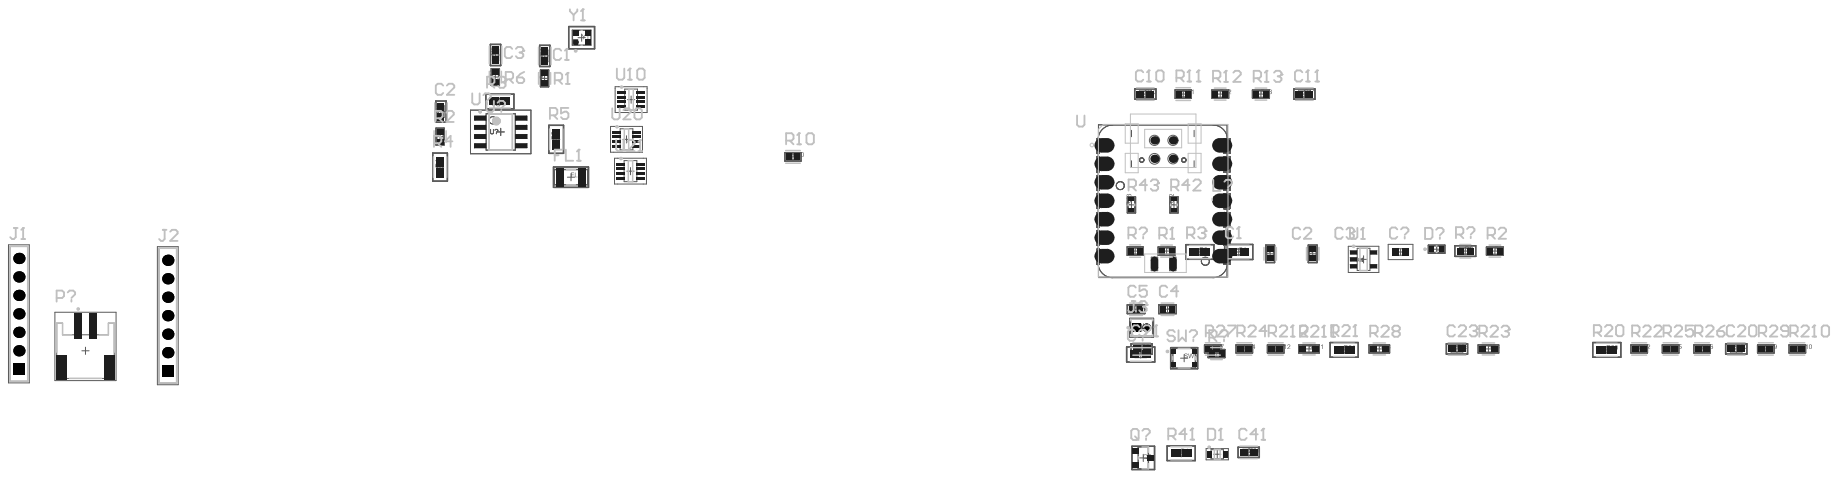
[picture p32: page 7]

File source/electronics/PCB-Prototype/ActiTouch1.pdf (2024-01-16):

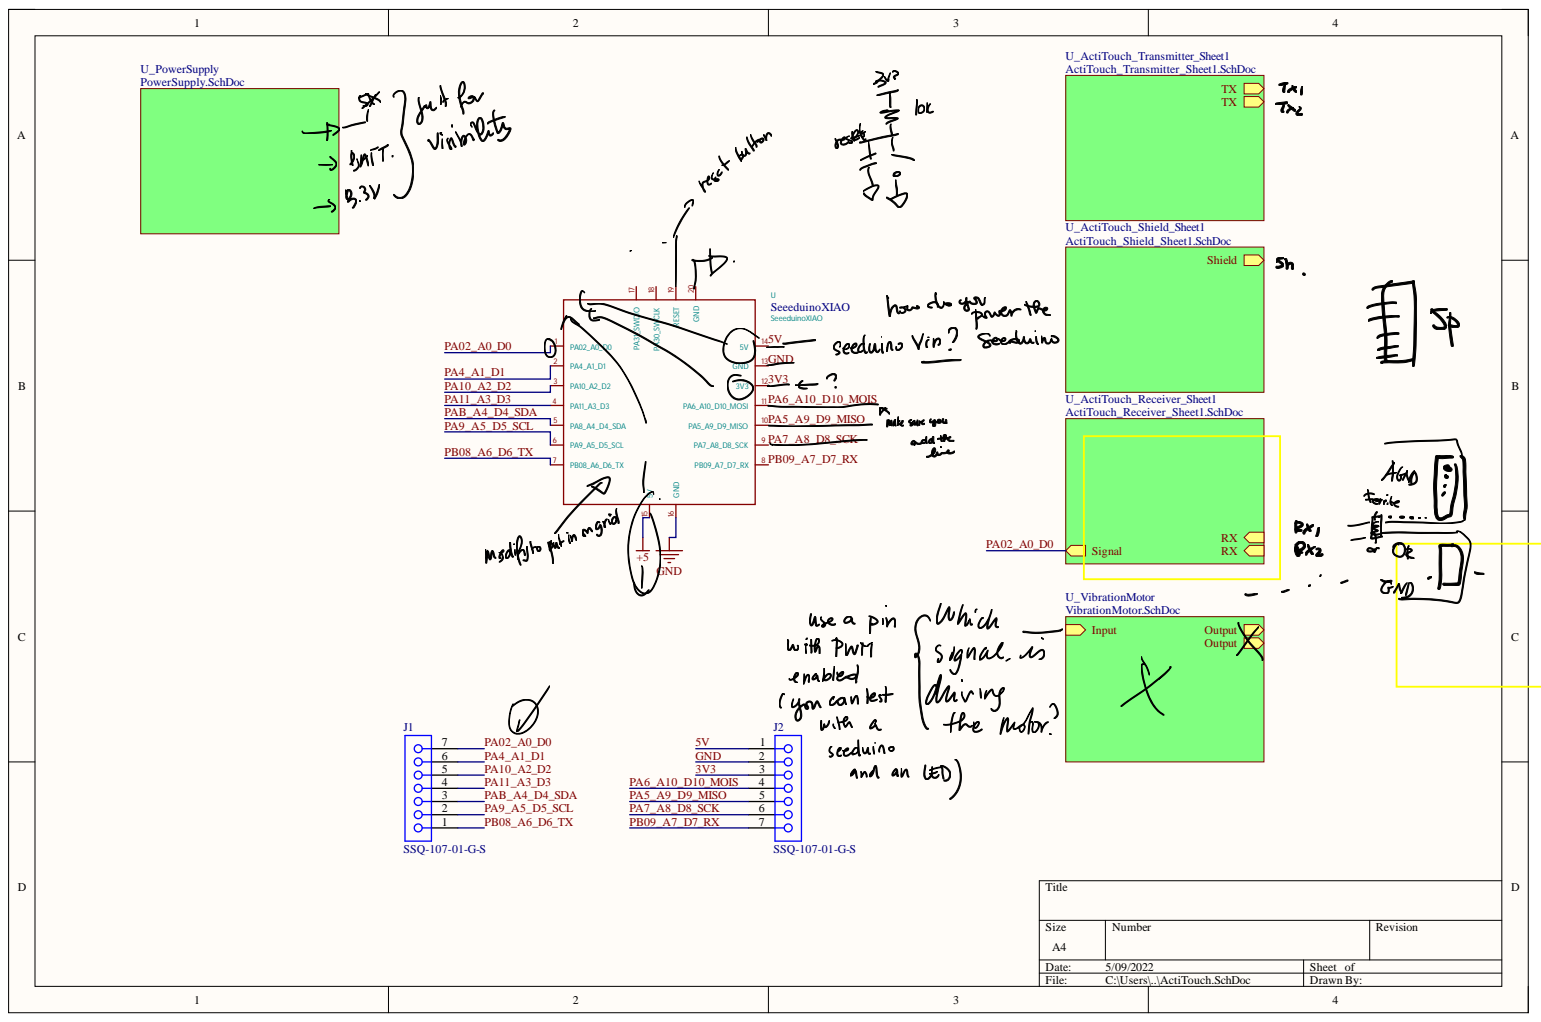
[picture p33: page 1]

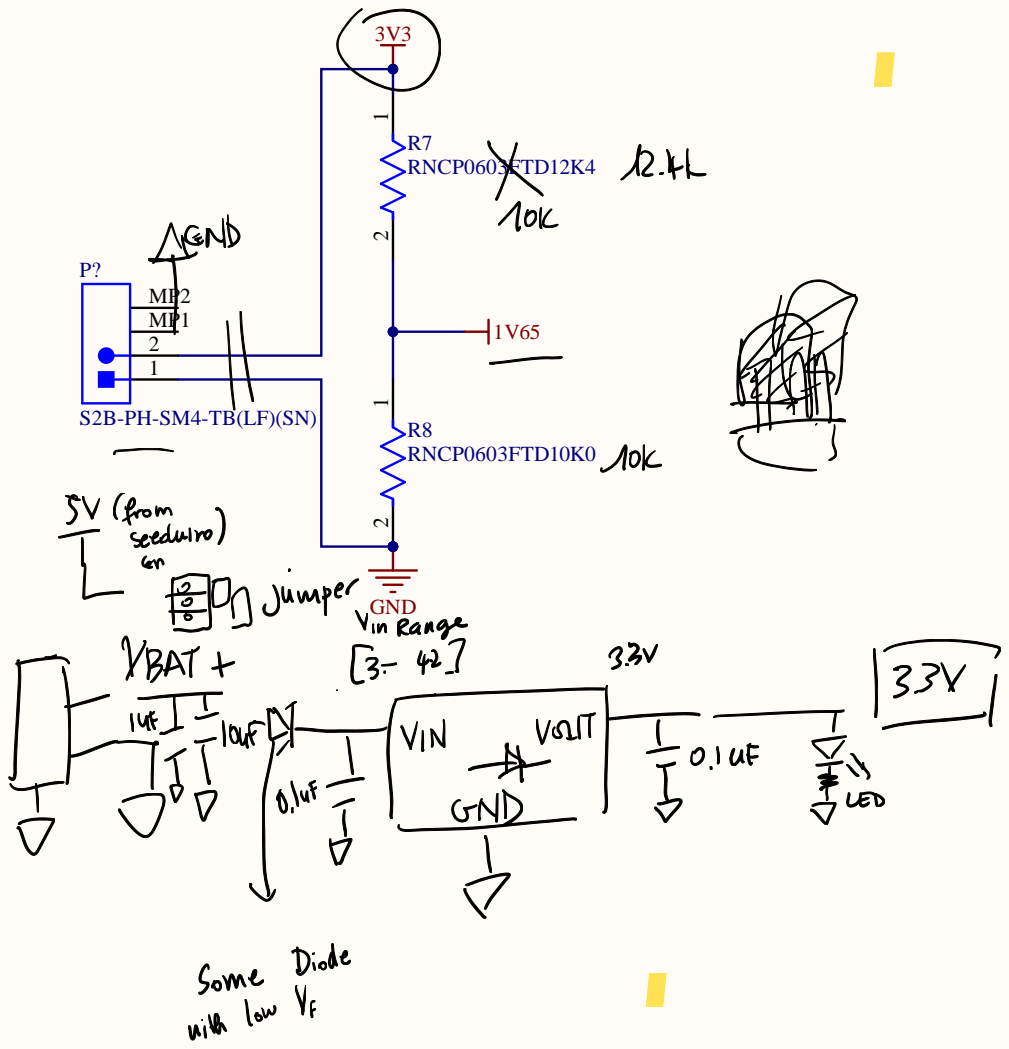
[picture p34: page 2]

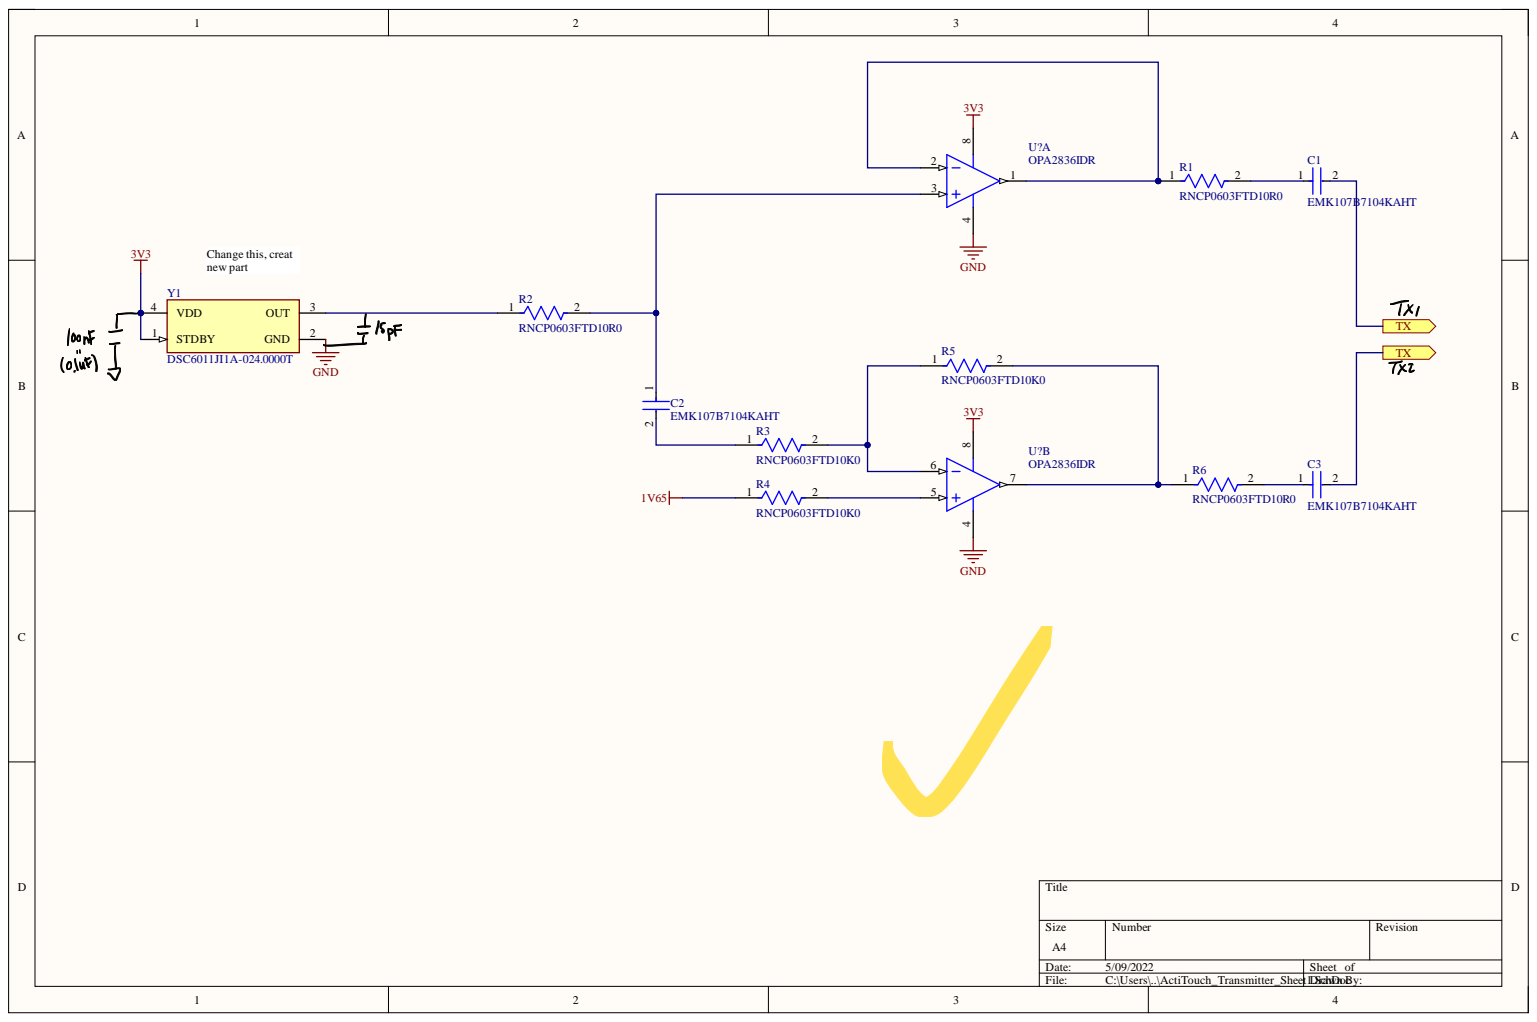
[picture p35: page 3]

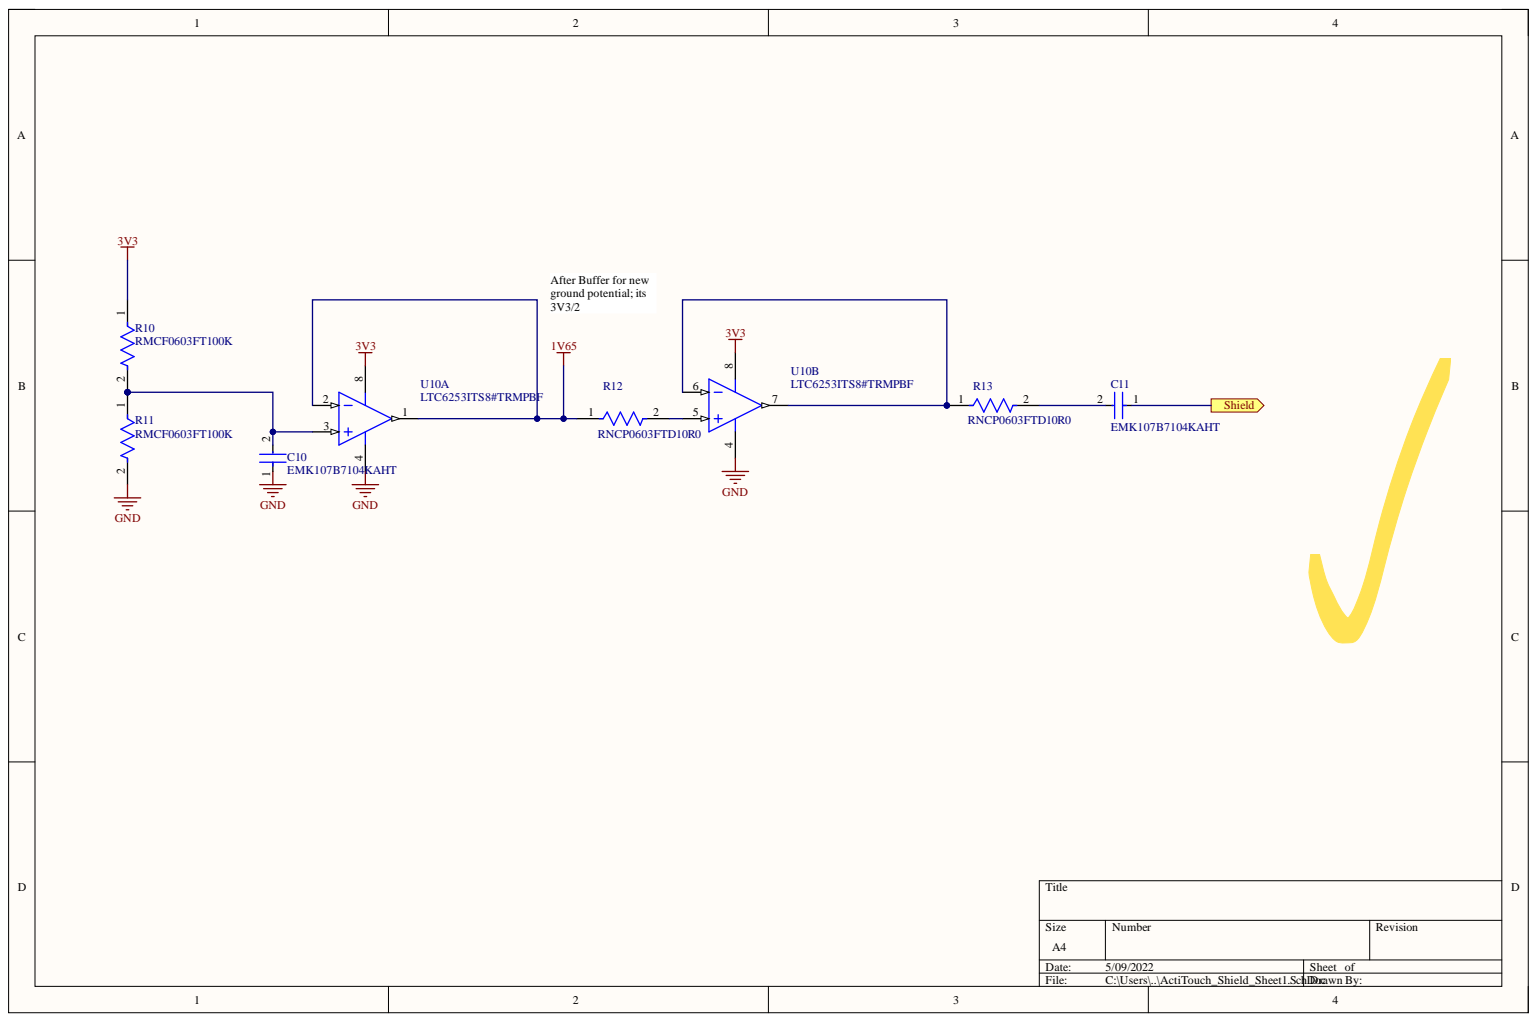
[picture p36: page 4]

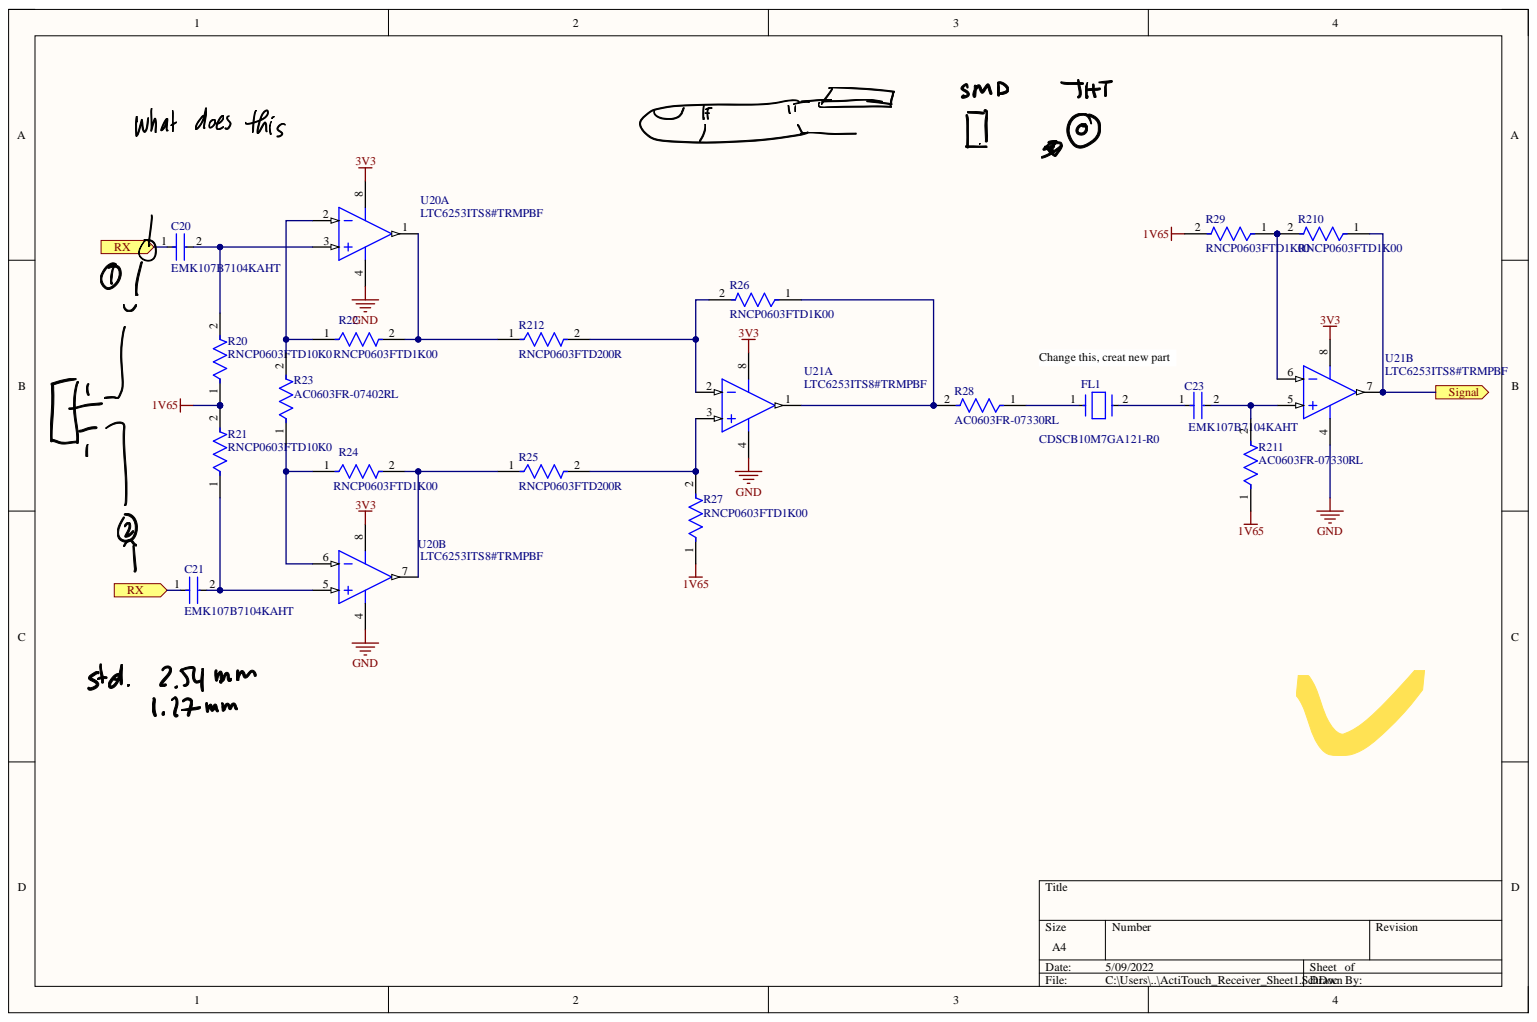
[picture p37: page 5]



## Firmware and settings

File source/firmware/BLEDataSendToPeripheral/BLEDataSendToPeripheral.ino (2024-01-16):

#include "arduinoFFT.h"
#include <ArduinoBLE.h>

/*Filter and Sampling*/ 
#define SAMPLES 128         //Must be a power of 2
#define SAMPLING_FREQUENCY 10000 //Hz, must be less than 10000 due to ADC

/*Threshold and Hysterese*/
#define HYST 0.006
#define THRESHOLD 0.024

/*Digial Pins*/
#define MOTOR_PIN 8
 
arduinoFFT FFT = arduinoFFT();
/*FFT Variables*/
double vReal[SAMPLES];
double vImag[SAMPLES];

unsigned int sampling_period_us;
unsigned long microseconds;
float averageEnergy ;


// variables for button
bool oldPinchState = false;
bool pinchState = false;

void setup() {
  Serial.begin(9600);

    pinMode(LED_BUILTIN, OUTPUT);
    pinMode(MOTOR_PIN,OUTPUT);
    pinMode(0,INPUT);

    sampling_period_us = round(1000000*(1.0/SAMPLING_FREQUENCY));

  // initialize the Bluetooth® Low Energy hardware
  BLE.begin();

  Serial.println("Bluetooth® Low Energy Central - LED control");

  // start scanning for peripherals
  BLE.scanForUuid("19b10000-e8f2-537e-4f6c-d104768a1214");
}

void loop() {
  //digitalWrite(LED_BUILTIN, LOW);
  // check if a peripheral has been discovered
  BLEDevice peripheral = BLE.available();

  if (peripheral) {
    // discovered a peripheral, print out address, local name, and advertised service
    Serial.print("Found ");
    Serial.print(peripheral.address());
    Serial.print(" '");
    Serial.print(peripheral.localName());
    Serial.print("' ");
    Serial.print(peripheral.advertisedServiceUuid());
    Serial.println();
    
    if (peripheral.localName() != "Ring") {
      return;
    }

    // stop scanning
    BLE.stopScan();

    controlLed(peripheral);

    // peripheral disconnected, start scanning again
    BLE.scanForUuid("19b10000-e8f2-537e-4f6c-d104768a1214");
  }
}

void controlLed(BLEDevice peripheral) {
  // connect to the peripheral
  Serial.println("Connecting ...");

  if (peripheral.connect()) {
    Serial.println("Connected");
  } else {
    Serial.println("Failed to connect!");
    return;
  }

  // discover peripheral attributes
  Serial.println("Discovering attributes ...");
  if (peripheral.discoverAttributes()) {
    Serial.println("Attributes discovered");
  } else {
    Serial.println("Attribute discovery failed!");
    peripheral.disconnect();
    return;
  }

  // retrieve the LED characteristic
  BLECharacteristic ledCharacteristic = peripheral.characteristic("19b10001-e8f2-537e-4f6c-d104768a1214");

  if (!ledCharacteristic) {
    Serial.println("Peripheral does not have LED characteristic!");
    peripheral.disconnect();
    return;
  } else if (!ledCharacteristic.canWrite()) {
    Serial.println("Peripheral does not have a writable LED characteristic!");
    peripheral.disconnect();
    return;
  }

  while (peripheral.connected()) {
    // while the peripheral is connected

    /*SAMPLING*/
    for(int i=0; i<SAMPLES; i++)
    {
        microseconds = micros();    //Overflows after around 70 minutes!
     
        vReal[i] = analogRead(A0)*(3.3/1023.0);
        vImag[i] = 0;
     
        while(micros() < (microseconds + sampling_period_us)){
        }
    }
 
    /*FFT https://www.norwegiancreations.com/2017/08/what-is-fft-and-how-can-you-implement-it-on-an-arduino/*/
    FFT.Windowing(vReal, SAMPLES, FFT_WIN_TYP_HAMMING, FFT_FORWARD);
    FFT.Compute(vReal, vImag, SAMPLES, FFT_FORWARD);
    FFT.ComplexToMagnitude(vReal, vImag, SAMPLES);
   
    averageEnergy = 0;
    for(int i=1; i<(SAMPLES/2); i++)
    {

        averageEnergy += vReal[i];
    }
    
    averageEnergy =averageEnergy/(128*(SAMPLES-2)/2);
    Serial.println(averageEnergy,4);
    /*Touch detection with hysteresis*/
    if (averageEnergy >= THRESHOLD+HYST/2){
      digitalWrite(LED_BUILTIN, HIGH);
      digitalWrite(MOTOR_PIN, HIGH);
      pinchState = true;
    }
    if (averageEnergy <= THRESHOLD-HYST/2){
      digitalWrite(LED_BUILTIN, LOW);
      digitalWrite(MOTOR_PIN, LOW);
      pinchState = false;
    }
    if (oldPinchState != pinchState) {
      // pinch changed
      oldPinchState = pinchState;

      if (pinchState) {
        Serial.println("pinch");

        // button is pressed, write 0x01 to turn the LED on
        ledCharacteristic.writeValue((byte)0x01);
      } else {
        Serial.println("pinch released");

        // button is released, write 0x00 to turn the LED off
        ledCharacteristic.writeValue((byte)0x00);
      }
    }
  }

  Serial.println("Peripheral disconnected");
}

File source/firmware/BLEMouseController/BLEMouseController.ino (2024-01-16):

#include <ArduinoBLE.h>
#include "PluggableUSBHID.h"
#include "USBMouse.h"

USBMouse Mouse;
 
BLEService ledService("19B10000-E8F2-537E-4F6C-D104768A1214"); // Bluetooth® Low Energy LED Service
 
// Bluetooth® Low Energy LED Switch Characteristic - custom 128-bit UUID, read and writable by central
BLEByteCharacteristic switchCharacteristic("19B10001-E8F2-537E-4F6C-D104768A1214", BLERead | BLEWrite);
 
const int ledPin = LED_BUILTIN; // pin to use for the LED
bool MouseClick = true;
 
void setup() {
  Serial.begin(9600);
  while (!Serial);
 
  // set LED pin to output mode
  pinMode(ledPin, OUTPUT);
 
  // begin initialization
  if (!BLE.begin()) {
    Serial.println("starting Bluetooth® Low Energy module failed!");
 
    while (1);
  }
 
  // set advertised local name and service UUID:
  BLE.setLocalName("Ring");
  BLE.setAdvertisedService(ledService);
 
  // add the characteristic to the service
  ledService.addCharacteristic(switchCharacteristic);
 
  // add service
  BLE.addService(ledService);
 
  // set the initial value for the characeristic:
  switchCharacteristic.writeValue(0);
 
  // start advertising
  BLE.advertise();
 
  Serial.println("BLE Peripheral");
}
 
void loop() {
  // listen for Bluetooth® Low Energy peripherals to connect:
  BLEDevice central = BLE.central();
 
  // if a central is connected to peripheral:
  if (central) {
    Serial.print("Connected to central: ");
    // print the central's MAC address:
    Serial.println(central.address());
 
    // while the central is still connected to peripheral:
  while (central.connected()) {
        if (switchCharacteristic.written()) {
          if (switchCharacteristic.value()) {   
            Serial.println("LED on and mouse click");
            digitalWrite(ledPin, LOW); // changed from HIGH to LOW
            if(MouseClick){
              Mouse.click(1);
              MouseClick = false;
            }    
          } else {                              
            Serial.println(F("LED off"));
            digitalWrite(ledPin, HIGH); // changed from LOW to HIGH 
            MouseClick = true;    
          }
        }
      }
 
    // when the central disconnects, print it out:
    Serial.print(F("Disconnected from central: "));
    Serial.println(central.address());
  }
}
